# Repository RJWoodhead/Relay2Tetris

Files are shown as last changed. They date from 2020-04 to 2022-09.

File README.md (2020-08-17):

# Relay2Tetris

In 2019, I had the great privilege of being able to see the [FACOM 128B](/Documents/FACOM-128B.pdf) computer in operation at Fujitsu's company museum. Delving into the technical details of how this machine worked only increased my admiration for the engineers who designed it. This has inspired me to create my own relay-based computer as a hobby project.

A few years prior I was introduced to the [Nand2Tetris](https://www.nand2tetris.org/) course, which I highly recommend. The HACK CPU that students implement in the course is a masterpiece of minimalist CPU design, so it was a natural target for my ambitions.

The goal of this project is to completely implement the HACK CPU in relay logic, and also to provide other relay-computer builders with a set of standard board-level relay logic CPU components, such as registers, adders, and so on.

# August 2020 Project Status Video

YouTube Video (https://youtu.be/P-tVBMidEhQ)

# Project Reports

* [Conversion of the idealized HACK CPU architecture to a physical model that addresses timing considerations](/Design.md).
* [Component-level HACK simulator](/Simulator.md).
* [40-Channel Daisy-chainable Raspberry Pi IO Expansion Board](/IOExpander.md).
* [The War on Voltage Drop](/Voltage.md).
* [Register Board](/Register.md).
* [Zuse Adder/Subtractor/Incrementor](/ZuseAdder.md).
* [8 Function Boolean Logic Unit](/LogicUnit.md).
* [2:1 Mux + NOT / Breadboard](/MuxNot.md).
* [Arithmetic-Logic Unit](/ALU.md).

# Reference Files

* [Useful EasyEDA scripts](/EasyEDA.md).
* [Hardware Test scripts)(HardwareTests).
* [Gerber Files for all boards](/Gerber).
* [Bills of Materials for all boards](/BOMs). (Note: does not include optional components like relay coil voltage drop resistors, voltage regulators, etc., as they will rarely if ever be needed. BOMs are for fully-populated boards including any breadboard relays)
* [Datasheets for various hardware components](/Datasheets).
* [YouTube project playlist](https://www.youtube.com/playlist?list=PL5v_4nsiG1zsZgzh9NE4S_au2oJwVJGt1).

The fleshing-out of this archive is an ongoing project; please be patient with the author.

# Recent Update History

2020-08-17: Assembled and tested the [Arithmetic-Logic Unit](/ALU.md).

2020-08-06: Updated all the board design documents, improved the hardware tests, did some project cleanups. Added a project status video.

2020-07-20: Launched the [War on Voltage Drop](/Voltage.md). Redesigned all boards based on the results (see individual board pages for details). Created new IO Expander Daughterboard. Added BOMs for all boards.

# To-Do List

* Clock and Sequencer - in design.
* Program Counter & Branch Unit - in assembly.
* Program ROM and RAM - optional, may design as proof of concept.

# Surplus Board Availability

Due to minimum quantity requirements, I have extras of most of the various versions of the various boards. If you want one, email me at trebor@animeigo.com and we'll work something out.

# Acknowledgements

Given that I am a programmer by trade, and thus a clueless n00b at hardware design, I am indebted to those who know better than me, including, but not limited to:

[Harry Porter's Relay Computer Project](http://web.cecs.pdx.edu/~harry/Relay/) and [Technical Paper](http://web.cecs.pdx.edu/~harry/Relay/RelayPaper.pdf)

[The Relay Computer Blog](https://relaycomputer.co.uk/)

[The Clicks Relay CPU](http://clicksrelaycpu.blogspot.com/?view=classic)

FACOM 128B Information:

* http://museum.ipsj.or.jp/en/computer/dawn/0012.html
* https://hackaday.com/2019/12/06/visiting-the-facom-128b-1958-relay-computer/

The complete Nand2Tetris course can be found at: https://www.nand2tetris.org/

# License

The materials in this repository (except for those provided by outside sources) are licensed under the [Creative Commons Attribution-NonCommercial-ShareAlike 4.0 International (CC BY-NC-SA 4.0)](https://creativecommons.org/licenses/by-nc-sa/4.0/).

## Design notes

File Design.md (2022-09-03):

# HACK CPU design

The [HACK CPU](https://www.nand2tetris.org/project05) is a minimalist CPU design, but for simplicity, the Nand2Tetris hardware simulator assumes idealized hardware with no gate delays. In the real world of clicky relays, a more detailed design is required. In particular, extra internal registers are needed to break up potential cycles (such as when a register is both the input to and destination of an ALU operation).

This design is a work-in-progress and will undergo significant revision as the actual hardware gets built.

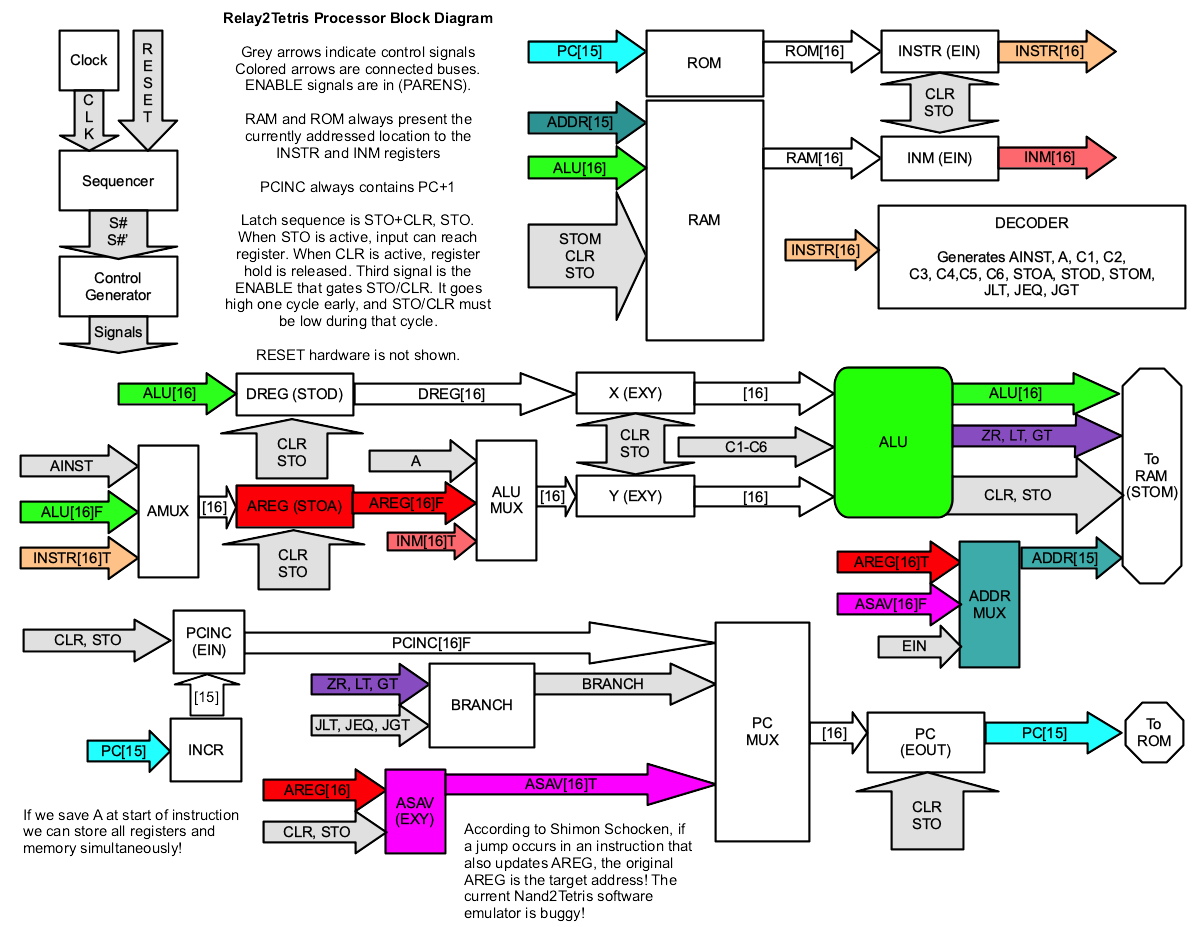
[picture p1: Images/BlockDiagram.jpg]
Block diagram for the expanded design


The computer a "tick-tock" clock that sequences through an 10-state loop per instruction. The states are then converted into control signals via a matrix or finite-state machine.

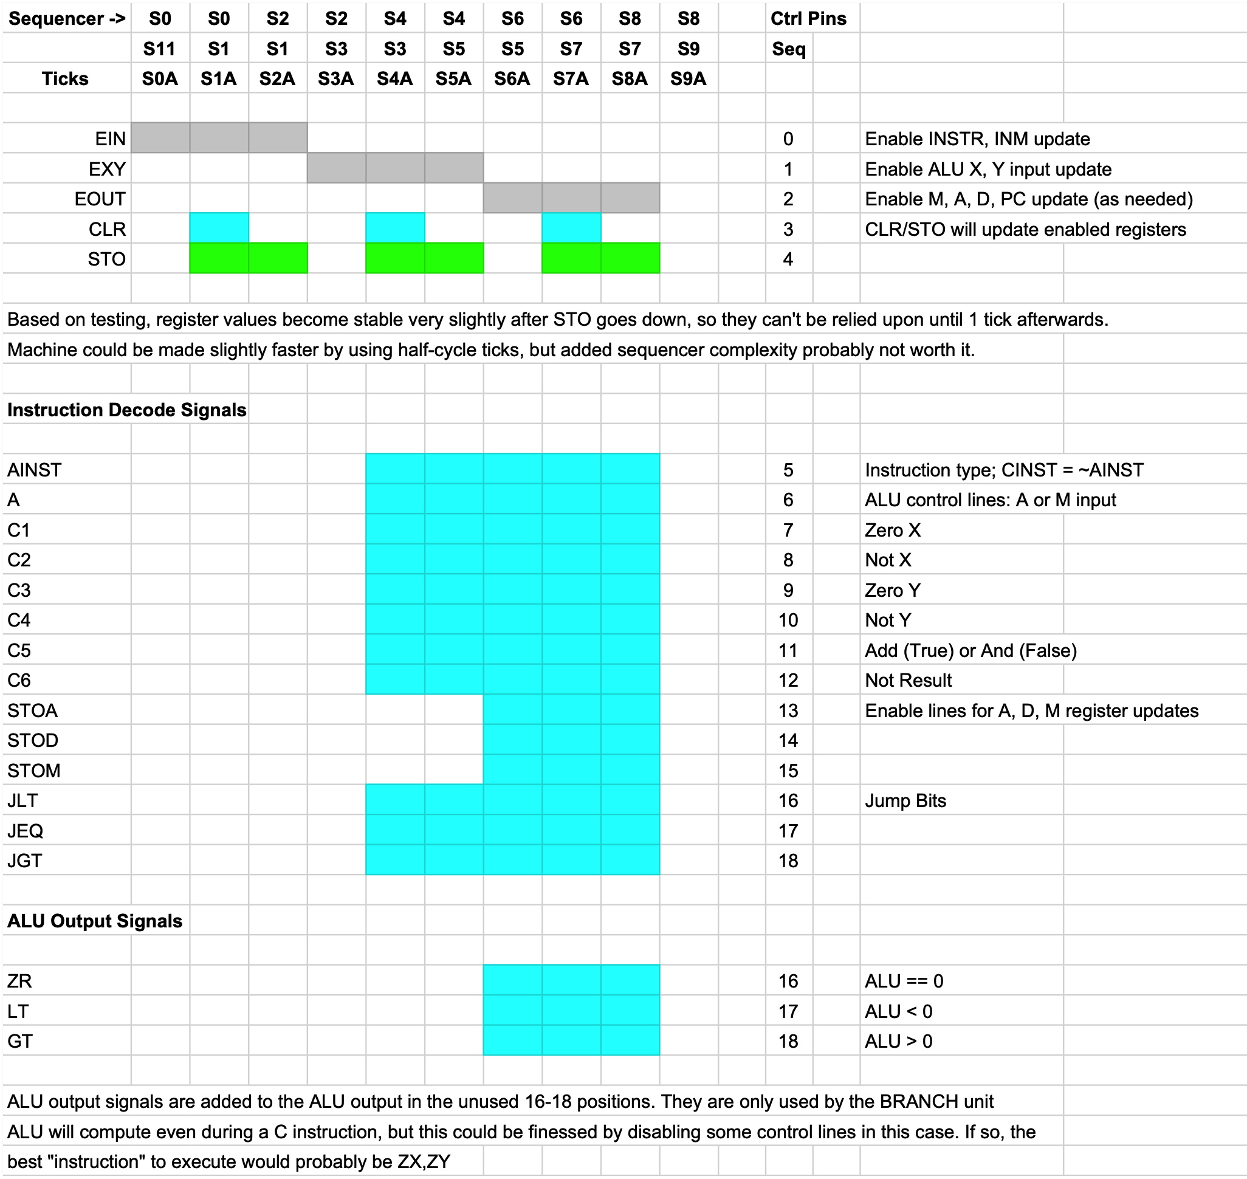
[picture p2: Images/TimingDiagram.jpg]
Instruction State Matrix


The clock and sequencer design will be heavily influenced by the excellent work done on the [Relay Computer Blog](https://relaycomputer.co.uk/2014/09/sequencing-control-design-overview).

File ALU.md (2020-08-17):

# Arithmetic-Logic Unit Assembly

The ALU is the first multi-board assembly in the project. It consists of:

* Two input data registers, X and Y. In the full computer, the X register is loaded with the value of D,
and the Y register is loaded with either A or M (using a multiplexer to select the desired input).

* Two Mux-Not boards, ZXNX and ZYNY. These first use the multiplexer to select either the input data or zero,
and then the Not unit to optionally negate the result. Thus, the ZXNX board can generate 0, -1, X and ~X,
and the ZYNY unit can generate 0, -1, Y and ~Y.

* An AND board and an ADD board, both of which are fed the outputs of ZXNX and ZYNY.

* A final Mux-Not board, which selects either desired AND or ADD output, and then optionally negates it.
This generates the output data value.

The ALU thus has 6 control lines, ZX (Zero X), NX (Negate X), ZY (Zero Y), NY (Negate Y), ADD (if 0, the AND output is used),
and NR (Not Result).

Surprisingly, the resulting ALU can compute all of the following values:

0, 1, -1, X, Y, ~X, ~Y, -X, -Y, X+1, Y+1, X-1, Y-1, X+Y, X-Y, Y-X, X&Y and X|Y

Actually, these are just the operations that are defined as part of the Hack machine language.
There are also some other [undefined operations of various utility](https://medium.com/@MadOverlord/14-nand2tetris-opcodes-they-dont-want-you-to-know-about-f3246831d1d1) that the ALU can perform.

# Physical Assembly

The boards are assembled using some [simple 3D-printed brackets](/STL) and connected using custom IDC cables.

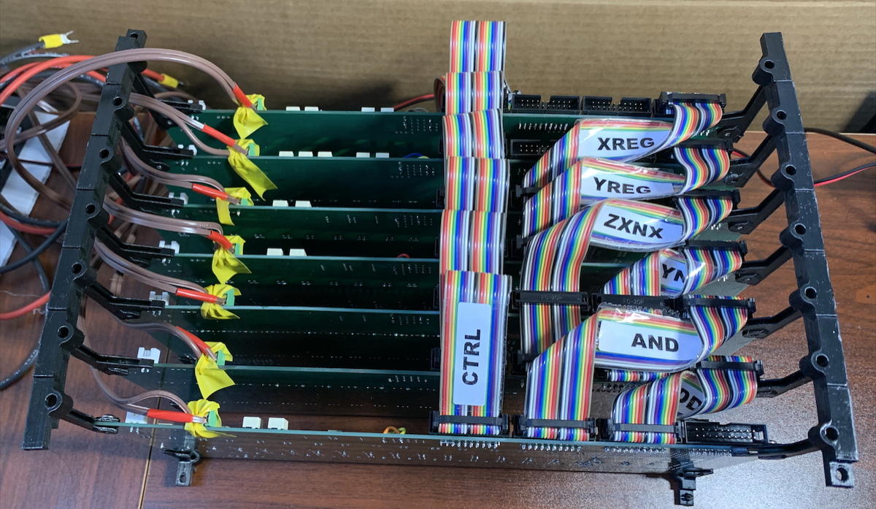
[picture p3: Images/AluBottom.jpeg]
16 Bit Logic Unit 1.0


# Testing

The ALU flawlessly completes the test script at a clock speed of 100 hz; it starts to become slightly unreliable at ~200 hz. Voltage drops are negligible, typically 100-150 millivolts. The drivers on the IO Expander provide a little over 10 volts when driven by the 12 volt input, but have no problems driving the control relays on the all boards. This bodes well.

Here is a video of the board being exercised.

YouTube Video (https://youtu.be/6PPwGQYELfU)

# Resources

* [Board Test Script](/HardwareTests/ALU.py).

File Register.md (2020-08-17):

# 16 Bit Register

Note: Please read [The War on Voltage Drop](Voltage.md) for context on the revision history of the PCB boards.

The Relay2Tetris project uses dual-pole, dual-throw (DPDT) relays. These have two independent circuits (the poles), each of which has an input and two outputs. When the relay is not energized, the inputs are connected to the normally-closed (NC) outputs, and when energized, the inputs are connected to the normally-open (NO) outputs.

The core element of the register is the self-latching relay circuit. In this circuit, when the BIT relay that holds the data is energized, one of the poles is used to complete a HOLD circuit that connects the relay coil to the power source. So once it gets energized, it stays energized. The second pole of the BIT relay is used to control the output of the register.

However, this circuit is also routed through the NC part of a second relay, the Clear (CLR) relay. Thus, when the CLR relay is energized, the HOLD circuit is broken. This circuit is hilighted in red in the illustration below.

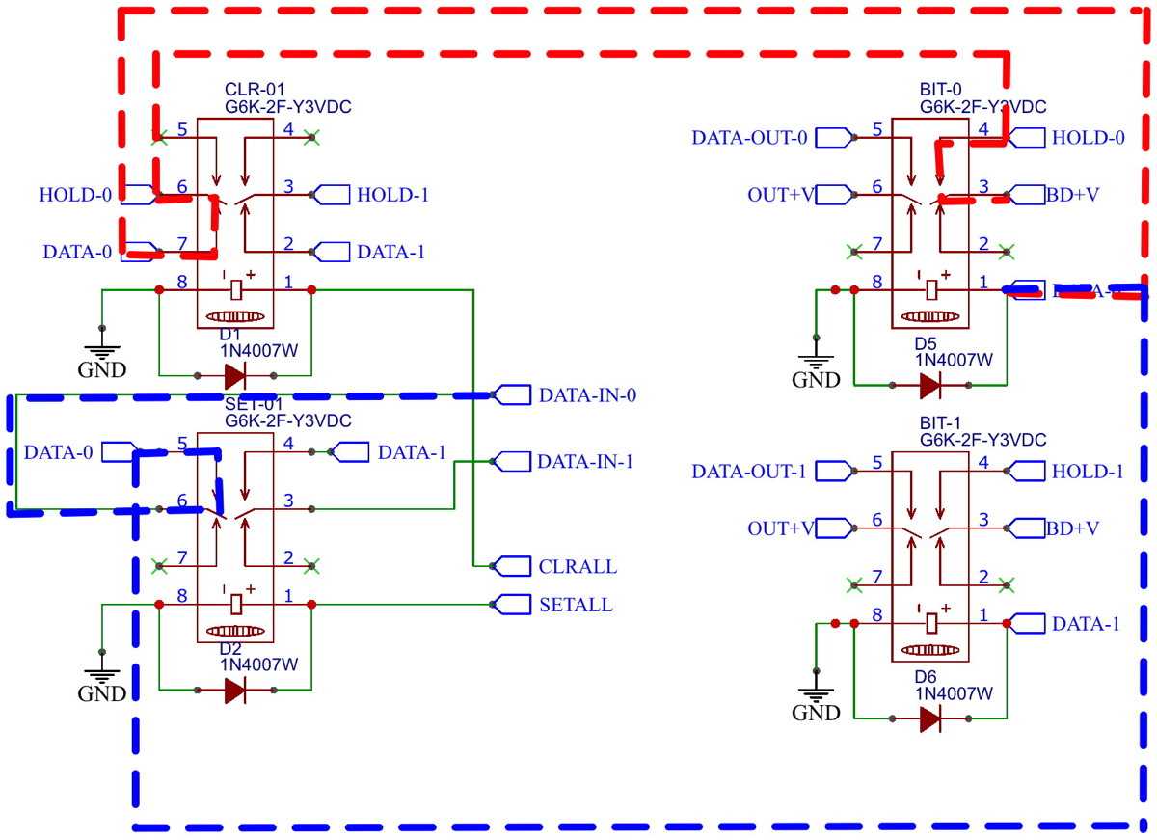
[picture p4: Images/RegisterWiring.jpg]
2 Bit Register Circuit


The second half of the circuit is the SET circuit. This is a relay that uses a NO part to gate the DATA-IN bit to the BIT relay coil, shown in blue above. When the relay is not energized, the BIT relay is isolated from the DATA-IN; it therefore maintains its state and is not affected by changes in DATA-IN.

Thus, the behavior of the circuit is as follows:

SET | CLR | Behavior
--- | --- | -------------------
Off | Off | BIT relays hold their value.
Off | On  | BIT relays reset to 0.
On  | Off | BIT relays are OR'd with incoming DATA
On  | On  | BIT relays are set to incoming DATA.

The usual control sequence for updating the register is thus SET+CLR (to replace the contents of the register), followed by SET alone (to ensure the data is being maintained by the HOLD circuit), followed by neither (to isolate the register from the inputs).

Since the CLR and SET relays have two poles, they can support two BIT relays. Thus, the basic building block is a 4-relay unit that stores 2 bits.

Repeat this 2-bit register 8 times, and the result is a 16-bit register.

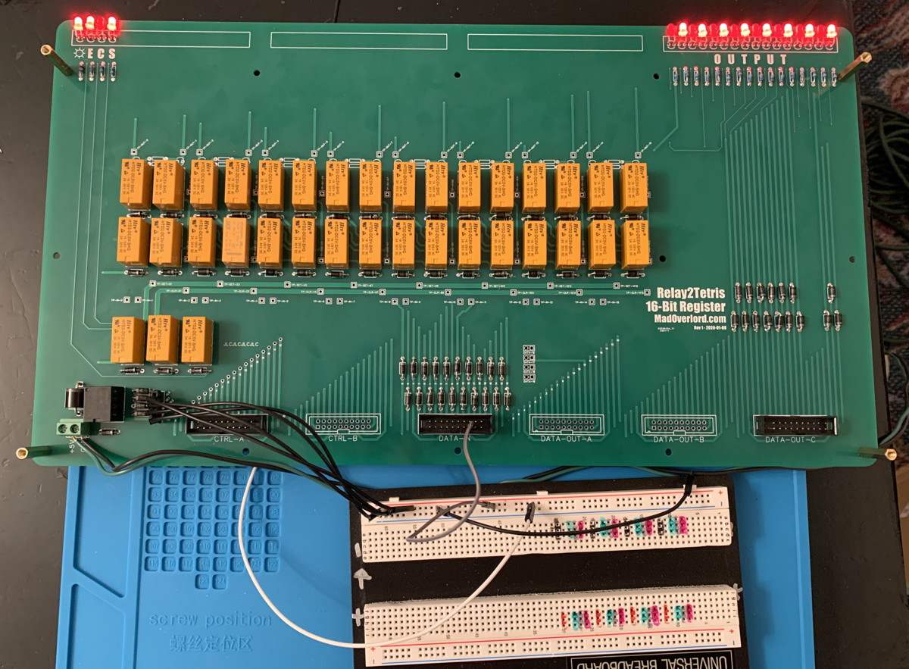
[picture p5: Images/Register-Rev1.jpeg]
16 Bit Register Rev 1.0


The Revision 1.0 board used inexpensive 5V through-hole relays. While fully functional, I did run into a few problems, the most confusing one being a voltage drop "gotcha" with the MIC2981 driver chips (see the [IOExpander](/IOExpander.md) writeup for details). After experimenting with the board at length, I designed a Revision 2.0 board that used 3V relays, and also moved to using surface mount components.

This allowed me to increase the component density and shrink the board significantly. Also, the 3V relays, while 3x as expensive as the cheap 5V ones, also switch 4x faster! So all in all, a good deal! In addition, I added a optional 2:1 multiplexer on the DATA-IN lines, as many of the registers in the final design have two possible inputs.

# Revision 2.0 Features (many of these also in 1.0)

* Onboard 3V3 regulator.

* Optional diode isolation of inputs and outputs.

* Control signals are ACT (Active, board is powered), ENA (Enable, board responds to control signals), SET, CLR, and MUX (controls whether DATA-0 or DATA-1 input is read). ACT and ENA can be jumpered to be always-on.

* All control inputs power isolation relays; this means an input signal only has to power one relay, even if the signal controls multiple relays on the board. This minimizes the current flowing through the ribbon cables. So for example, the SET control signal activates a single SETALL relay; that relay controls the 8 SET relays on the board. Each relay draws about 33 milli-amps @ 3V, and each relay contact is limited to about 1 amp, so using both contacts on a relay, you can source 2 amps = 60 relays using a single isolation relay. In practice, you don't want to approach this, so ~40 relays per isolation relay is a reasonable limit. The 16-bit register board has 40 relays driven by power sourced from the ACT relay.

* Control signals set by jumpers.

* Optional 2:1 Input Multiplexer.

* Optional signal passthrough connectors.

* Jumperable passthrough of the 4 unused IDC-20 signal lines on input to output.

* 3V0 relays running at ~3V3. Selectable 3V3 or 5V0 signal output.

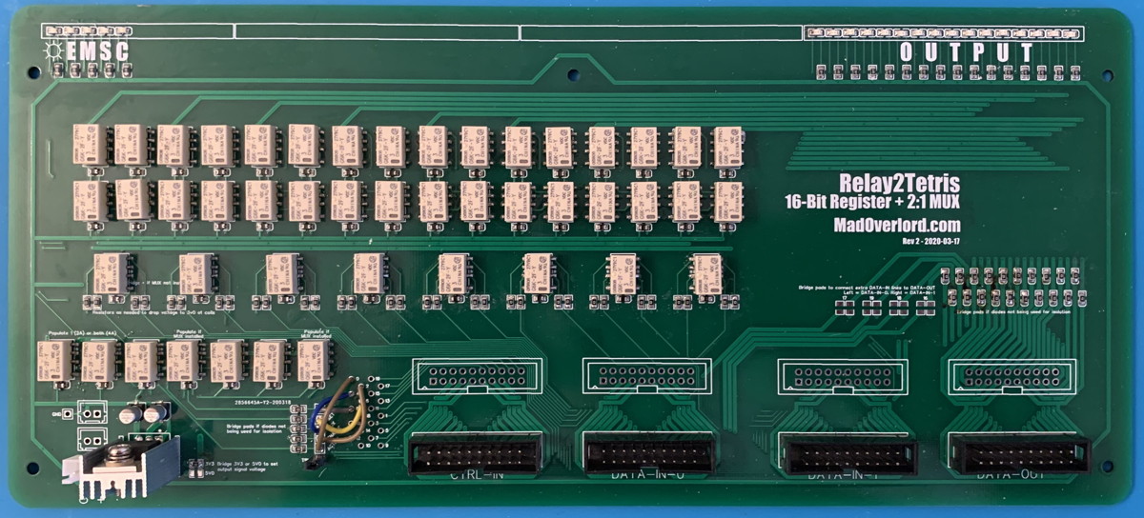
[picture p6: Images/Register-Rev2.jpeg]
16 Bit Register Rev 2.0


A detailed [Board Test Script](/HardwareTests/Register16.py) is also available. It requires my IOExpander board.

YouTube Video (https://www.youtube.com/watch?v=gMaYLL4p_do)

A short video showing the Revision 2.0 board being tested is available on [YouTube](https://www.youtube.com/watch?v=gMaYLL4p_do).

# Revision 3.0

Based on my experience with the Revision 1.0 and 2.0 boards, I have designed a Revision 3.0 board with several improvements:

* Removed signal passthrough connectors because that function can be handled with custom cables that are easier to configure.

* Removed power isolation relays, they are not really needed.

* Removed input and output isolation diodes as they are not needed in boards where the inputs are isolated via relays and the outputs do not connect to relay coils, so backfeed to relays is not possible. I had read that backfeed was an issue with relay circuits but I went overboard and didn't think it all the way through. A version of the Rev 3.0 board with isolation relays is available in the EasyEda project in case it is needed for a specific board.

* Changed ENABLE relay so that it controls the SET and CLR relays by disconnecting their GND connections.

* Changed trace sizes to match the expected current loads.

* Made 3V3 regulator optional.

* Moved passthrough jumpers to the rear of the board where possible to save space.

* Eliminated passthrough of pins 17-20 on the IDC connector (again, can be done with cabling), but added jumpers to connect 3V3 and GND to pins 19 and 20. This may be handy if using the output to directly drive a small satellite component, such as a display board.

* Moved traces closer to the edge of the board and rearranged everything to maximize the central area available for a relay array. Currently can handle a grid of 23x6 relays.

I have not yet manufactured any Revision 3.0 boards, but the designs are contained in the EasyEda projects (links below). The core layout (which is actually an edge layout!) will be used in subsequent functional boards.

Note: It turns out there is a design error with the ENABLE circuit in the Rev 3.0 boards that I am working on addressing. See [this note](LogicUnit.md#board-design-mistake) for more details.

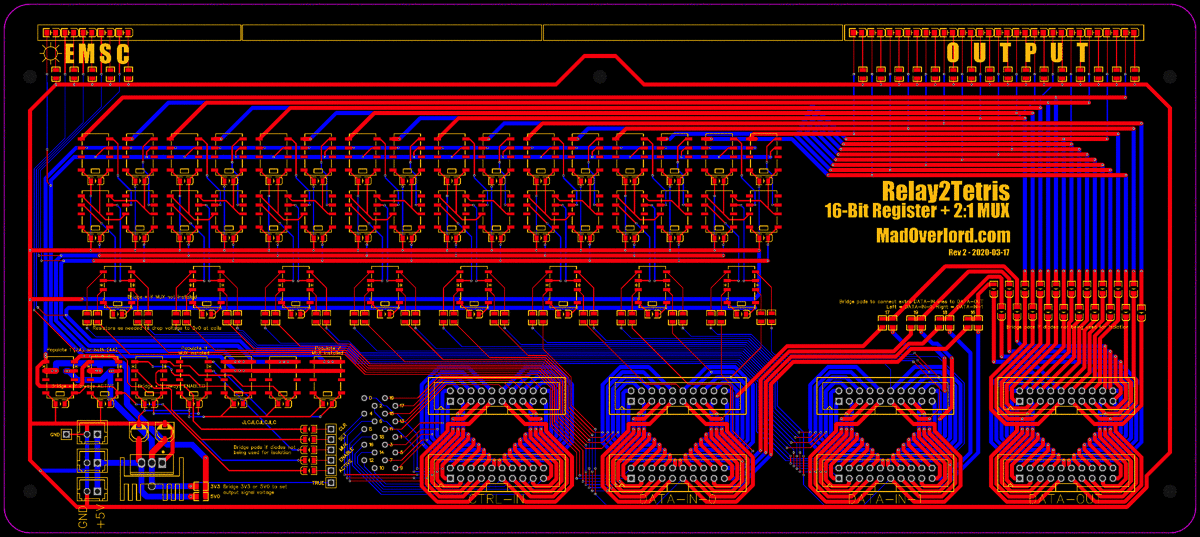
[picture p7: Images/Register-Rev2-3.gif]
16 Bit Register Rev 2.0/3.0 Comparison


# Revision 4.x

As a consequence of the [The War on Voltage Drop](Voltage.md), the Rev 4.0 board has many improvements:

* Fatter traces to reduce resistance of signal wires.

* Two voltage supply inputs, one of which can be regulated. Board voltage and output voltage can be selected from these.

* Removed ACTIVE signal as it is not really needed.

* Added RESET signal that clears register even when ENABLE is not raised. In the 4.0 board, the RESET may not work correctly if both ENABLE and SET are also raised and the data bus is non-zero. In practice this should not be a problem since RESET would be raised for many cycles, but this has been fixed in the 4.1 board.

* Since there was space on the board, also added a bit test functional unit. There are two independent test channels (one for each pole in the relays), and for each bit position you can specify that the bit has to be True, False, or Don't Care. The tests can also be set up into subtests that only look at a sequence of bits (so you can test high and low bytes separately, for example). Finally, there are outputs for each of the bits, two additional relays for implementing special purpose logic, and you can then jumper all of these to indicator leds and the upper 4 bits of the 20 pin IDC data connectors as well as any of the control lines. A typical use for this would be detecting when the register is zero or negative.

* In the 4.1 revision, unused parts of the board have been filled with additional breadboard relays.

* In 4.2, improvements were made to the board silkscreen labels (but no layout changes).

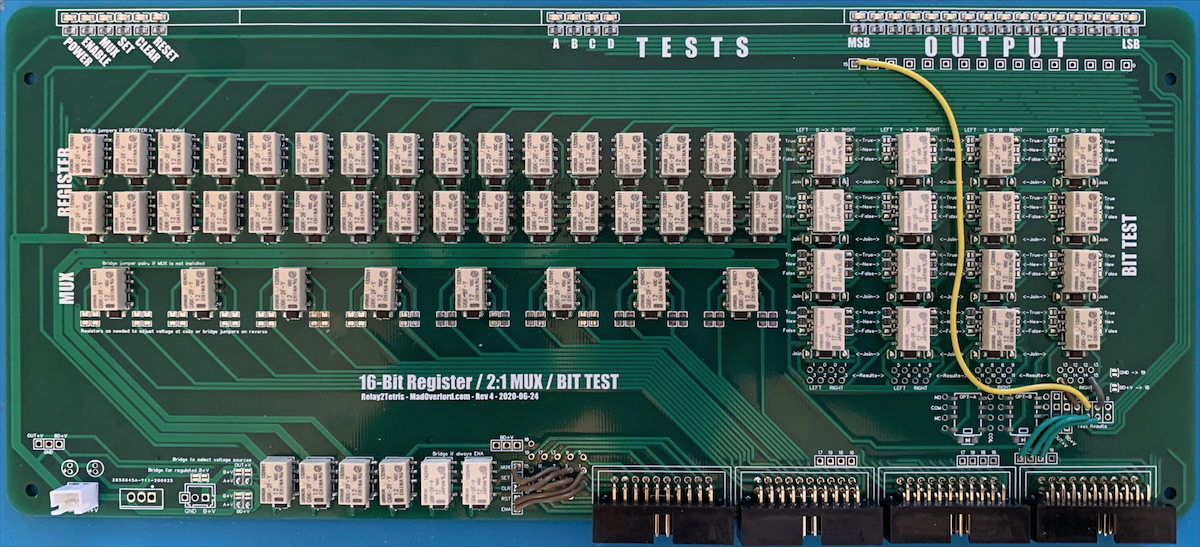
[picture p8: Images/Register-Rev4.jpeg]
16 Bit Register Rev 4.0


In the above image, the board is wired to detect 0, -1, and <0.

# Resources

* [Board Test Script](/HardwareTests/Register16.py).

* [EasyEda Project](https://easyeda.com/MadOverlord/16-bit-register), [Gerber Files](/Gerber/Register.zip) and [BOM](/BOMs/Register.csv) for the latest revision of the board.

* Boards were manufactured by [JLCPCB](https://jlcpcb.com/). Parts were sourced from [LCSC](https://lcsc.com/) and [Digikey](https://www.digikey.com/).

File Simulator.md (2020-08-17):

The [Relay2Tetris simulator](/Simulators) simulates the proposed HACK CPU implementation at the board-level, and updates the state of control signals and component inputs and output every clock tick.

Eventually, this simulator will have the ability to interface with the actual hardware, and gradually migrate more and more component functions to the actual device.

The Tests subdirectory contains a set of test programs for the simulator, adapted from the Nand2Tetris HACK tests.

**NOTE**: The current version of the simulator is running an older version of the hardware design that does not match the [current design](design.md). The simulator will be updated to match the hardware design when larger chunks of the hardware are being integrated.

# Running the simulator

Usage: python3 validate.py [Test name (subfolder of Tests folder)] {Trace Level: [N]one|[I]nstruction|[C]lock|[S]ettle}

Test folder [xxx] will contain up to 4 files.

* [xxx].hack : The machine code source file (output of the Nand2Tetris assembler) - required

* [xxx].asm : Human-readable source code (input to the Nand2Tetris assembler)

* [xxx].tst : Validation test script (input to the Nand2Tetris emulator)

* [xxx].cmp : Validation comparison results

If [xxx].tst is present, the validator runs the test script and compares the output to the contents of the [xxx].cmp file. If not, the validator just runs the machine code.

To make parsing simpler, there is a restriction on the test scripts: there can be only one output-list, and the formatting is ignored.

The load, output-file, and compare-to commands are ignored because they are implied by the files in the test folder, and these files need to be loaded before the script is executed.

For convenience, the validator recognizes when the machine has entered the infinite-loop end condition and exits script repeat loops early in this situation.

The default trace level is [I]nstruction, which provides machine state at the start of each instruction cycle. [C]lock lets you see the internal state of all signals at each machine clock. [S]ettle shows that plus the process of settling on the hardware state. [N]one just reports the results of the validation.

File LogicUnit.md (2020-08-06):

# 8 Function Logic Unit

Note: Please read [The War on Voltage Drop](Voltage.md) for context on the revision history of the PCB boards.

This board generates the 6 useful logic functions (AND, OR, XOR, NAND, NOR and XNOR) as well as the two useless ones (TRUE and FALSE) on two 16-bit inputs.

# Revision 1.0

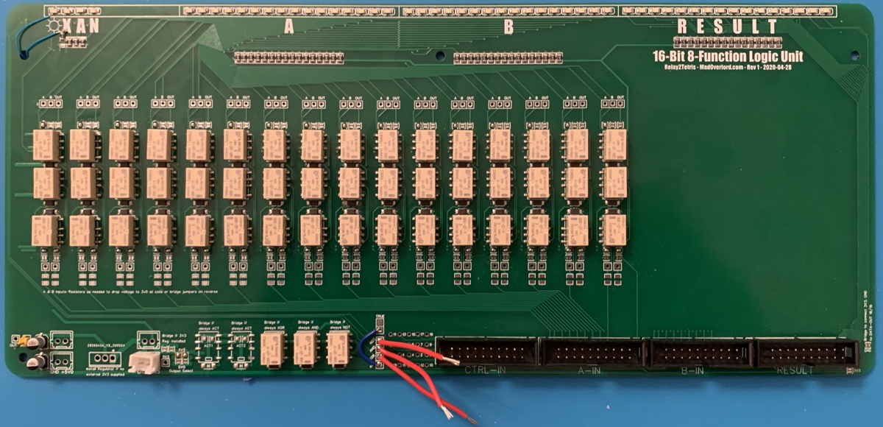
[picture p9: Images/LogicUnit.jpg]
16 Bit Logic Unit 1.0


Operation selection is done through 3 control signals (AND, XOR, and NOT). There are two stages to the unit; in the first, AND and XOR are computed as needed;
they are then OR'd and optionally NOTted. OR is generated by computing both AND and XOR at the same time.

The circuit design is inspired by the Zuse adder, in that the operation selection signals for AND and XOR energize two circuit paths, and the state of two relays
is controlled by the input bits; this determines whether or not the signals get through the relays to the NOT relay. Since AND and XOR are exclusive to each other (AND(a,b) != XOR(a,b)), there is no possibility of backfeed between the circuits and their outputs can simply be connected together to OR them.

That said, my battles with backfeed are not over; see below for an important gotcha!

The desired operation can be hardwired for the entire board or on a per-bit basis using solder bridges.

YouTube Video (https://youtu.be/KSzZ73obGIc)

A short video showing the Revision 1.0 board being tested is available on [YouTube](https://youtu.be/KSzZ73obGIc).

# Board Design Mistakes

One of my goals with the board design was to minimize power usage by disabling relays when the board was not ACTIVE. This was done by routing all of the relay grounds onto
an ENABLE circuit, and connecting that to GND via a relay. If that relay wasn't activated, no connection to GND, and none of the other relays could operate.

This design fails if there is any connection, however convoluted, between the ENABLE circuit and GND. And unfortunately, when the board is connected to the IO Expander (and thus,
the Raspberry Pi), there is such a connection: backwards through any relay coil, out through one of the connectors, to the IO Expander, and then through the data line's pulldown
resistor!

To paraphrase Ian Malcolm, "Electricity finds a way." :(

This situation is made even worse because +3V3 is routed through the ACTIVE LED to the ENABLE circuit. This means that when the board is connected to the IO Expander, that LED
(and some of the DATA leds) glow faintly.

The board still operates as expected, but the mistake is troubling and it's a recipe for weird problems down the line. Thus I am redesigning this board, and all the other boards
that I revised to use this ENABLE system, so that all relays always connect directly to GND.

In the meantime, the workaround is to not install the ENABLE relays and solder-bridge the board so it's always ENABLED. This makes the ENABLE circuit equivalent to GND.

A second error is that if the NOT relay is not populated, and NOT is not activated, the NC relay connections need to be bridged in order for the other logical functions to operate properly. I omitted solder jumpers for this functionality. The workaround is to use some 0-ohm SMT resistors as jumper wires.

# Revision 2.0

16 Bit Logic Unit 2.0

Revision 2.0 of the board incorporates all of the lessons learned during the War on Voltage Drop. In addition, the unused space on the board has been filled with a relay breadboard that may come in handy; this is configured like the bit test unit on the register board, so it can easily be wired to do bit value tests if needed.

This board has been manufactured and tested. The only mistake I've noticed so far is that I swapped the labels on the ALWAYS and NEVER NOT-Control jumpers. This has been corrected in the 2.1 revision.

# Resources

* [Board Test Script](/HardwareTests/LogicUnit.py).

* [EasyEda Project](https://easyeda.com/MadOverlord/relay-boolean-logic-unit), [Gerber Files](/Gerber/Logic.zip) and [BOM](/BOMs/Logic.csv) for the latest boards.

* Boards were manufactured by [JLCPCB](https://jlcpcb.com/). Parts were sourced from [LCSC](https://lcsc.com/) and [Digikey](https://www.digikey.com/).

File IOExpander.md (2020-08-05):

# Raspberry Pi 40-channel IO Expander

In order to control and test the relay-based functional modules this project will require, the ability to control a large number of data channels is required. For example, the 16-bit register board requires 2 16-bit data inputs, 5 bits of control input, and produces 16 bits of data output.

This is far more channels than the Raspberry Pi natively provides, and so some sort of IO Expansion device is needed.

*Note: I am not an electrical engineer. Everything I've learned has been from reading and trying things out. Therefore, take everything here with a grain of salt. That said, so far it's worked really well!*

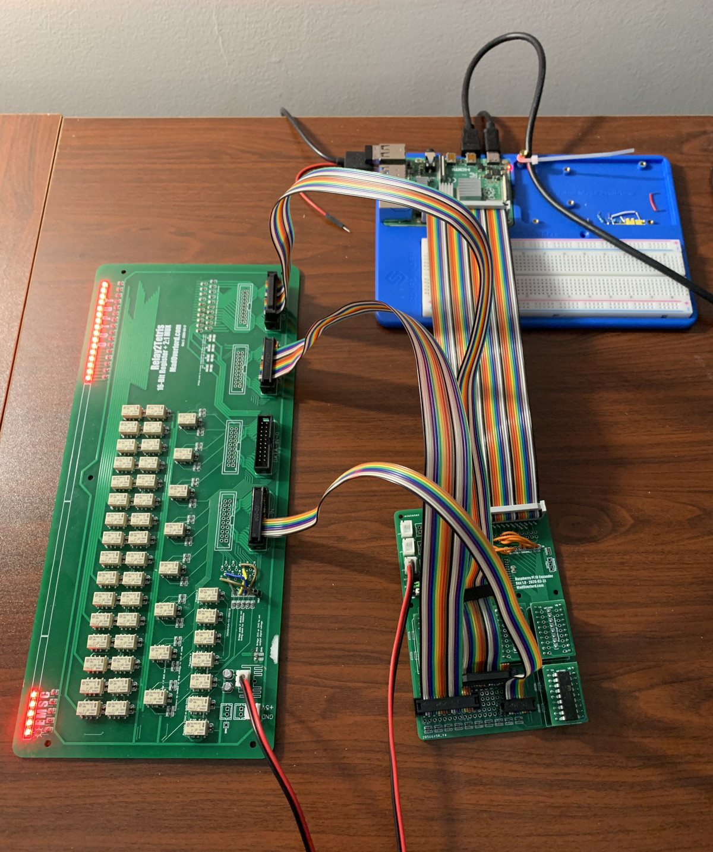
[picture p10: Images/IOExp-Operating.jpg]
Operating IO Expander


The common approach in this situation is to use one or more [MCP23017](/Datasheets/MCP23017.pdf) bidirectional IO port chips; each provides 16 channels, and up to 8 can be connected to the Raspberry Pi. However, controlling relays adds a layer of complexity because each relay requires ~30ma of current and the maximum amount of current the chip can provide is 25ma per pin, and 125ma total.

Another chip that people often use when connecting circuits to the Raspberry Pi is the [TXS0108e](/Datasheets/txs0108e.pdf) bidirectional level converter. It is an 8-channel chip that can increase or reduce the voltage of a signal, so it can (for example) convert from 3.3v to 5.0v. However, it too is limited to 50ma per signal and 100ma total.

Therefore, to drive relays, we need to put something between the MCP23017 and the relays that can provide the needed current. What I settled on was the [MIC2981](/Datasheets/mic2981.pdf) driver array; it can provide 8 channels of up to 500ma per channel.

* **One thing about the MIC2981 to be aware of**: under load, the output voltage on a signal line will sag from 1.5-2.0v. On the datasheet, this is cryptically (to a n00b like me) listed as "Collector-Emitter Saturation Voltage". What this means is that if you power the chip at 5v0 (5 volts), what your relays will see is ~3V3 (3.3 volts), which is at the low end of what the relay will respond to. And since the sag is affected by the total amount of current the chip is sourcing, the more signal lines that are high, the lower the voltage on those lines. Before I understood this, I was going nuts trying to figure out why Revision 1 of my relay register board (which used 5V relays) would become unreliable when I asked it to store numbers with lots of set bits! The solution is to provide the MIC2981 with about 1.7v more input voltage than the desired output voltage. In my case, to keep things simple, in the Revision 2 relay board (shown above), I provide 5V0 to the MIC2981 chips, and use 3V relays on the board (which are comfortable with voltages up to 4.5v, so giving them 3.3-3.5v is fine). This also lets me use a standard PC power supply, which provides both 3V3 and 5V0.

* As explained in [The War on Voltage Drop](Voltage.md), this turned out to be a mistake.

I tested using the MCP23017/MIC2981 combination on a breadboard, and then built a project-board version that was a complete rats-nest of wires. It worked, but it certainly wasn't pretty. Since I was going to need a significant number of IO channels, I decided to build a PCB version of the IO expander. This is what I came up with:

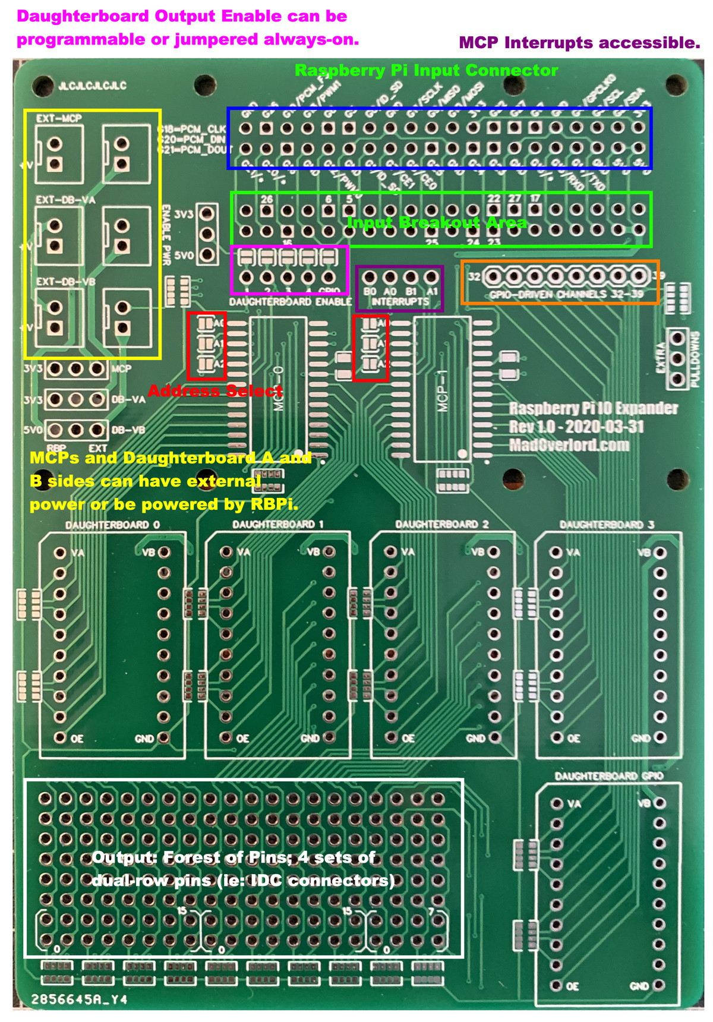
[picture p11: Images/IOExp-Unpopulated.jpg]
Unpopulated IO Expander


This board supports two MCP23017 chips (2x16 channels) plus 8 channels of direct GPIO from the Raspberry Pi. Up to 4 boards can be daisy-chained together. So you can have up to 128 bits of MCP IO, plus all the usual GPIO IO.

Features include:

* For flexibility, each group of 8 channels is routed through a small daughterboard, which is configured to accept one of the TXS0108e daughterboards that are commonly available from lots of different suppliers. In addition, I designed a compatible daughterboard that will accept a MIC2981 or can be jumpered as a passive passthrough. The daughterboard uses the through-hole variant of the MIC2981 because (a) I had some of them and (b) they are slightly cheaper than the surface mount version. Later on, I also created a voltage divider daughterboard for reducing the voltage of input signals.

  * There are pulldown resistor arrays on the input (MCP or GPIO) side of each daughterboard socket. My experience is that you need them for active devices like the MIC2981, but not for passives like the voltage divider (which is in effect its own pulldown). In particular, if you don't have the pulldowns on MIC2981s being driven by the RBP's GPIO, when you do a GPIO.cleanup() and the pins go to input mode, the MIC2981 inputs will float, and you may get spurious outputs.

* A forest of output pins make it easy to install IDC-style headers, or wire up custom connectors. The outputs also have a set of resistor arrays for output pulldown.

* The MCPs and the A and B sides of the daughterboards can receive their power from the Raspberry Pi or an external power source.

* The Enable signals that the TXS0108e boards require can be jumpered always-on or controlled by GPIO signals.

* Mounting holes for a Raspberry Pi. Typically, you'd mount the Pi above the IO Expander, so the Expander isn't a "Hat", it's a "Shoe".

A detailed [Board Test Script](/HardwareTests/MCPLoopback.py) is also available.

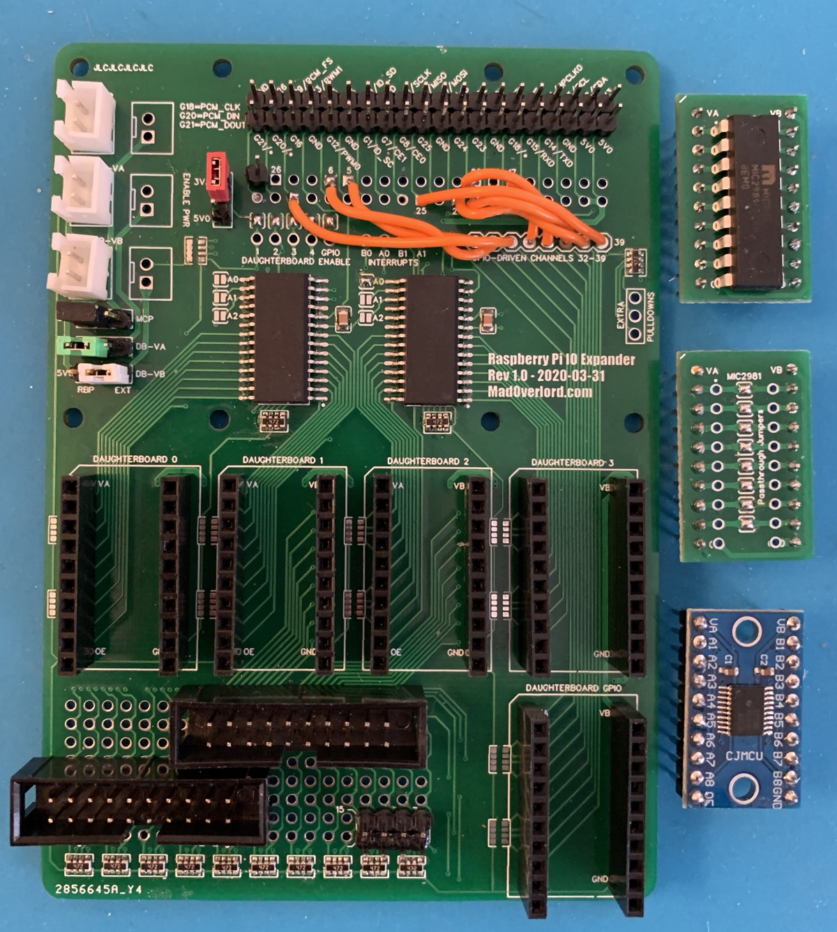
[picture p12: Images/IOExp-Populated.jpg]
Populated IO Expander


# Random Things I Learned

These are very simple things. Marvel at my n00bitude.

* Surface mount soldering is fun and easy, but the 0603 resistor arrays are a bit finicky; they tend to accumulate solder bridges. Using a pencil-tip soldering iron set at 280c and flicking the tip between bridged pads is a quick way to eliminate the bridges.

* You can test for bridges on the resistor arrays by measuring the resistance between adjacent pins on the non-ground side; if there is no bridge, the reading will be about 2x the resistor value. Note that this won't work on the first two pins of the arrays below the MCP pins, as the first pin is separate; it's connected to +V and the ~RESET line of the chip.

* The easy way to connect the solder jumpers is to use the soldering iron to heat both pads and then feed some solder onto the tip while stirring it around, then removing the tip. You always need to add a little solder to the tip even if there already is some on it, because the flux in the fresh solder helps surface tension do its magic. I also took one of my fine tips and bent the end into an L-shape to make it easier to contact both of the pads at the same time.

# Revision 2.0

Based on my experience with the Revision 1.0 boards, I have designed a Revision 2.0 board with several improvements:

* Solder jumpers for common GPIO hookups (so no nest of wires like in my populated board).

* Optional pulldowns on the underside of the daughterboard on both input and output lines, which may be more convenient than the pulldowns on the mainboard.

* Extra mount hole in the lower part of the board for a support standoff when stacking boards.

I have not yet manufactured any Revision 2.0 boards, but the designs are contained in the EasyEda projects (links below).

Here is a complete "full stack" consisting of a Raspberry Pi 4 and 4 IO Expander boards. It provides 2 x 16 bit MCP outputs, 20+4 bits of GPIO output (all using the MIC2981 daughterboards so they can drive relays), and 6 x 16 bit MCP inputs.

# Voltage Dividing Daughterboard

As part of [The War on Voltage Drop](Voltage.md), I needed a way to convert 12V0 signals from the PCBs down to 3V3 so they could be safely read by the MCP chips. I did this with a simple voltage 8-channel voltage divider circuit. Links to the project and Gerber files below.

The PC power supply I am using delivers about 11.4 volts on its 12V0 output.

In turn, the MIC2981 drivers output about 9.9v when given this input when under load. This is enough to drive relays on a board, as they have a must-operate voltage of 80% = 9.6v. However, it is something to be aware of in more stressful situations. The solution will be to increase the supply voltage to the B side of the 2981s on the IO Expander board to ~14v. 2981s can accept up to 50v, so there's no problem there. The relays can tolerate 150% of rated voltage, so giving them 15-2=13v should not be a problem.

Using the Rev 4.0 register board, with input voltage of 11.4v, the output voltage at the data connector is 11.37, almost no drop. After the voltage divider, we are down to 3.17v, which is more than enough; the MCPs will reliably read data to about 55-60% of the 3v3 nominal voltage.

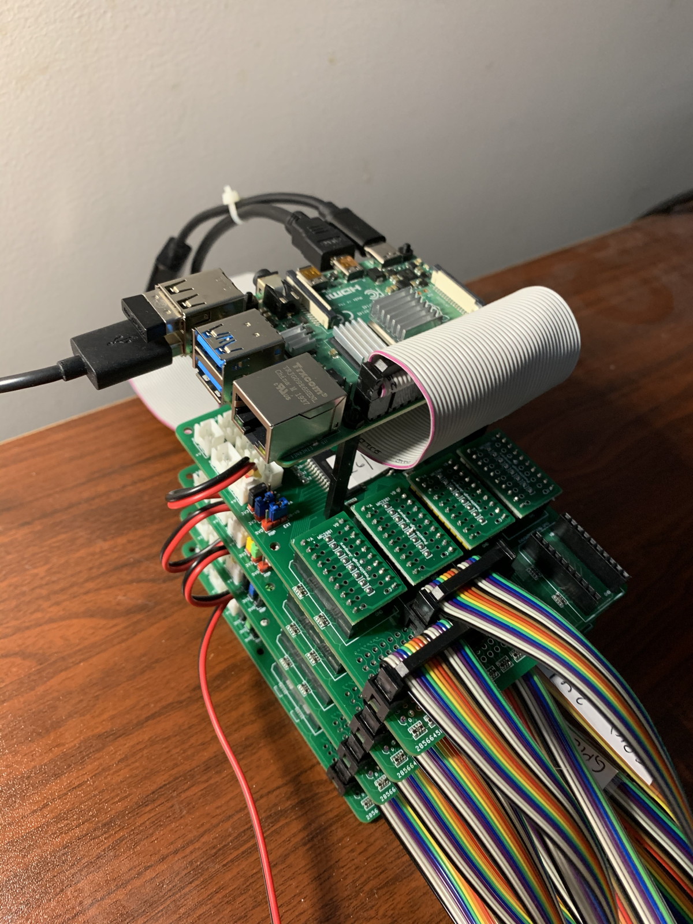
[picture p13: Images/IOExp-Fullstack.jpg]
IO Expander Stack


# Resources

* [Board Test Script](/HardwareTests/MCPLoopback.py)

* [Quick GPIO Test Skeleton](/HardwareTests/GPIO.py)

* IO Expander [EasyEda Project](https://easyeda.com/MadOverlord/rbp-io-expander), [Gerber Files](/Gerber/IO_Expander.zip) and [BOM](/BOMs/IO_Expander.csv).

* MIC2981 / Passthrough Daughterboard [EasyEda Project](https://easyeda.com/MadOverlord/io-expander-daughterboard), [Gerber Files](/Gerber/IO_Expander_Daughterboard.zip) and
[BOM](/BOMs/IO_Expander_Daughterboard.csv).

* Voltage Drop Daughterboard [EasyEda Project](https://easyeda.com/MadOverlord/io-expander-voltage-divider-daughterboard), [Gerber Files](/Gerber/IO_Expander_Voltage_Drop.zip) and
[BOM](/BOMs/IO_Expander_Voltage_Drop.csv).

* Boards were manufactured by [JLCPCB](https://jlcpcb.com/). Parts were sourced from [LCSC](https://lcsc.com/) and [Digikey](https://www.digikey.com/).

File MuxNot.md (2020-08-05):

# 2:1 Mux + NOT Board

Note: Please read [The War on Voltage Drop](Voltage.md) for context on the revision history of the PCB boards.

This board is pretty simple. It consists of a 2:1 input multiplexer connected to a NOT unit.

# Revision 1.0

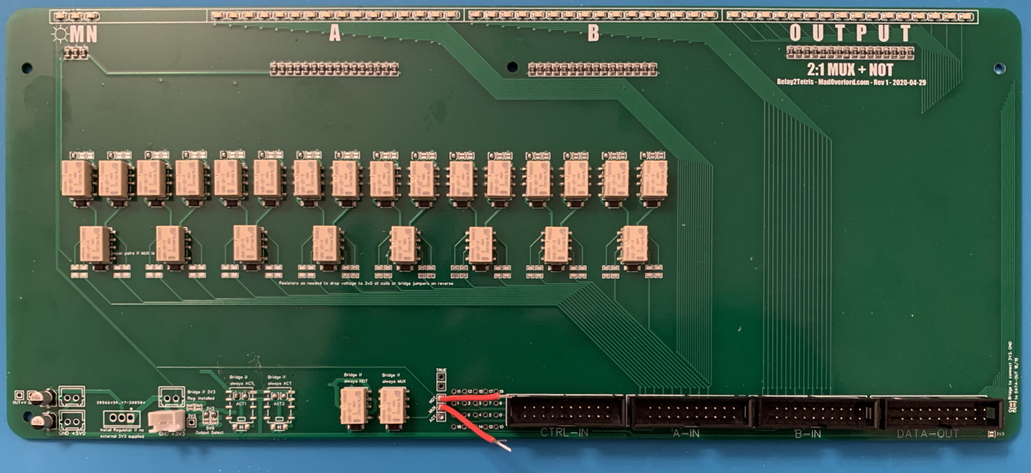
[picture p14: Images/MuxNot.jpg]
16 Bit Mux + Not 1.0


Two of these board will be used in the ALU to compute the ZERO and NOT operations on the X and Y inputs. ZERO is a simple matter of not connecting B-IN to anything! If the MUX bit is then set, the input to the NOT unit is all zeroes.

The desired operations can be hardwired for the entire board or on a per-bit basis using solder bridges.

YouTube Video (https://youtu.be/2-9iTJ1my6Y)

A short video showing the Revision 1.0 board being tested is available on [YouTube](https://youtu.be/2-9iTJ1my6Y).

Note: It turns out there is a design error with the ENABLE circuit in this board that I am working on addressing. See [this note](LogicUnit.md#board-design-mistake) for more details. The temporary workaround is to jumper the board so it is always ENABLEd.

# Revision 2.0

16 Bit Mux + Not 2.0

Revision 2.0 of the board incorporates all of the lessons learned during the War on Voltage Drop. In addition, the unused space on the board has been filled with a relay breadboard that may come in handy.

# Resources

* [Board Test Script](/HardwareTests/MuxNot.py).

* [EasyEda Project](https://easyeda.com/MadOverlord/16-bit-relay-2-1-mux-not), [Gerber Files](/Gerber/MuxNot.zip) and [BOM](/BOMS/MuxNot.csv) for the latest revisions.

* Boards were manufactured by [JLCPCB](https://jlcpcb.com/). Parts were sourced from [LCSC](https://lcsc.com/) and [Digikey](https://www.digikey.com/).

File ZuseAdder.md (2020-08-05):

# 16 Bit Zuse Adder

Note: Please read [The War on Voltage Drop](Voltage.md) for context on the revision history of the PCB boards.

The Zuse Adder is an amazing relay circuit created by computing pioneer [Konrad Zuse](https://en.wikipedia.org/wiki/Konrad_Zuse) in the late 1930s. A normal adder has 3 inputs (the two data bits A and B plus a carry-in bit) and two outputs (the result plus carry-out). This is quite straightforward, but suffers from the problem of carry-propagation delay. Each bit in the sum has to wait until the previous bit is computed in order to get its carry-in bit, so you have to wait for the carry states to ripple down the adder.

The Zuse Adder, on the other hand, has 5 inputs (the two data bits A and B, carry-in, **not-carry-in**, and true) and 3 outputs (the result, carry-out, and not-carry-out). By propagating both the carry state and its inverse, each bit adder always has at least 2 current sources (one of the carries plus the true input), and a clever combination of two 4PDT relays per bit can route these to the correct outputs (only two of which can be true), with no carry propagation delay (other than the electrons meandering down the circuit paths, of course).

It takes a while to wrap your head around exactly how this electromechanical magic trick works, but I've hilighted the connection paths in the [schematic PDF](/Documents/ZuseAdder.pdf) for each of the 8 possible cases.

* Note: I created an alternate EasyEDA schematic for the relays that organized the common and NO/NC contacts in a way that made the schematic simpler. It comes in two variants, one of which has the coils energized. This makes it easier to follow the connection paths.

But it gets better. Normally you set the inputs to the first bit of the adder to carry-in=OFF, not-carry-in=ON. But if you swap this and give the adder carry-in=ON, not-carry-in=OFF, it happily computes A+B+1. If you then set B=0, you have an A+1 incrementor.

And then it gets even better than that. In binary arithmetic, A-B is equivalent to A+(~B)+1. We can already do A+B+1, so if we add a circuit that can produce ~B, the circuit can also subtract! All of this for only 5 DPDT relays per bit!

# Revision 1.0

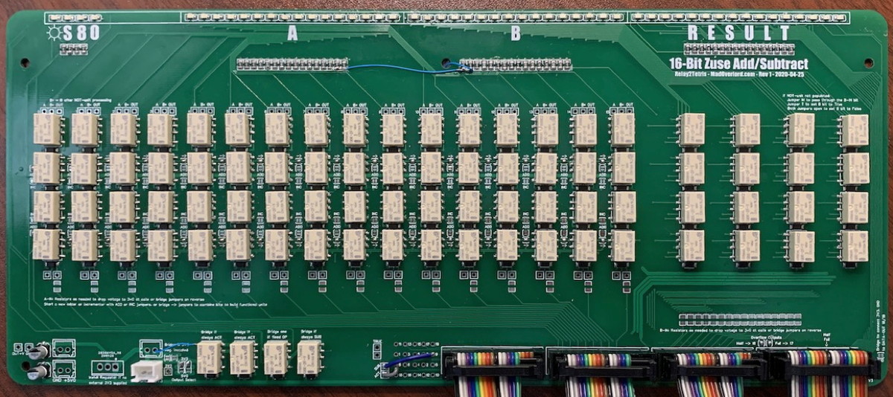
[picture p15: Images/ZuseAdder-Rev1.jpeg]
16 Bit Zuse Adder Rev 1.0


The revision 1.0 Zuse Adder/Subtractor uses the Revision 3.0 Register board as its template, so it has all of the "infrastructure" features of that board.

* 16 Bit Zuse Adder implemented as 4 DPDT relays per bit (+1 if Subtract required)

* Configurable as multiple independent n-bit adders or incrementors. Each bit has solder jumpers that can set the carry-in and not-carry-in to be the start of a new adder, a new incrementor, or carry from the previous bit. So for example, you can configure the board as 2 independent 8-bit adders.

* Optional NOT unit if subtraction is needed; 1 relay per bit.

* Optional outputs for the carry-out of bits 7 and 15 (useful for ALU condition codes).

A short video showing the Revision 1.0 board being tested is available on [YouTube](https://www.youtube.com/watch?v=ZFYi-r_6CD0).

While testing the Revision 1 board, I realized I had made a small mistake. All the relays and the ENABLE LED were connected to ground through the ENABLE relay, but the A and B data display LEDs were connected directly to ground. This meant that when power was provided to the board, there was a path from 3V3 through the power-on LED, then to the ENABLE line, and then backwards through any populated relay or its flyback diode to the associated data display LED, and then to ground. This caused all these LEDs to glow dimly. This did not affect function because as soon as the ENABLE relay connected everything to ground, everything corrected itself.

The solution to this was to cut the data display LED resistor ground connections and wire them to the ENABLE line; this is the blue wire in the photo above.

The other thing I didn't realize at the time was that if all you need is an incrementor, you don't need to populate the two B relays per bit; you just need to bridge their normally-closed pads. I did a quick test of this to create an 8-bit incrementor; a short video is up on [YouTube](https://youtu.be/ckB8yvfqFFo).

# Revision 2.0 / 3.0

16 Bit Zuse Adder Rev 3.0

The Revision 2.0 board design fixes the ground connection problem and adds bridges on the B relays so you can hardwire them to create a fixed adder with any value (with or without the +1 from configuring things as an incrementor). In my test of the incrementor setup, I set up an incrementor with a fixed B input of 0 (I just bridged the pads with small wires) to get a +1 result.

* Note: I created an alternate EasyEDA PCB Library entry for the B relays that included the solder jumpers. This meant they didn't have to be manually added to the schematic.

Note: It turns out there is a design error with the ENABLE circuit in the Rev 2.0 boards that I am working on addressing. See [this note](LogicUnit.md#board-design-mistake) for more details.

A second error is that if the NOT relay array *is* populated but the SUB activation relay *is not* populated, and SUB is not jumpered, the NC SUB relay connections need to be bridged in order for the adder to operate properly. I omitted solder jumpers for this functionality. The workaround is to use some 0-ohm SMT resistors as jumper wires.

I only ran into this error because I fully populated the board to test out the subtract function, and then removed the activation relays to configure the board for use in my prototype ALU.

I then incorporated the lessons from the War on Voltage Drop, resulting in the Rev 3.0 design. The one mistake I've noticed so far is a missing mounting hole in the top-right corner. This has been corrected in the Gerber files.

# Resources

* [The Z1: Architecture and Algorithms of Konrad Zuse’s First Computer](https://arxiv.org/pdf/1406.1886.pdf).

* [Konrad Zuse’s Legacy: The Architecture of the Z1 and Z3](https://www.semanticscholar.org/paper/Konrad-Zuse's-Legacy%3A-The-Architecture-of-the-Z1-Z3-Rojas/be8b813ffdd21a6d75172344f98ce4dcd67b2d44).

* [Board Test Script](/HardwareTests/ZuseAdder.py).

* [EasyEda Project](https://easyeda.com/MadOverlord/zuse-relay-adder), [Gerber Files](/Gerber/ZuseAdder.zip) and [BOM](/BOMs/ZuseAdder.csv) for latest revision of the board.

* Boards were manufactured by [JLCPCB](https://jlcpcb.com/). Parts were sourced from [LCSC](https://lcsc.com/) and [Digikey](https://www.digikey.com/).

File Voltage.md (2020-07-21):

# The War on Voltage Drop

As previously mentioned, I am an electronics n00b. This caused me to make a fundamental -- but fortunately, easily rectifiable -- mistake when originally designing the boards.

I chose to use 3 volt relays in the design because I thought it would make the interconnection to the Raspberry Pi easier, but to my chagrin, it ended up casting my electronics inexperience in a harsher light than I would prefer.

In any circuit, there is a voltage applied across the entire circuit. So for one of my relay circuits, this would typically be about 3.3 volts, as this was the standard signal voltage for the Pi. So if you measure the voltage from the voltage source to the ground, you'd get 3.3 volts.

The relays have a minimum reliable operating voltage of 80% of their rating; in this case that would be 2.4 volts. 3.3 is > 2.4, so this should be okay, right?

Nope.

What counts is the voltage drop across the relay (measured from one side of the relay coil to the other). That has to be at least 2.4 volts. And that voltage depends on the entire circuit.

You can think of the circuit as having three segments in series; the wires leading from the voltage source to the relay, the relay, and the wires leading from the relay to ground. The voltage drop across each segment is proportional to the resistance of each segment - so as long as the resistance of the wires is less than about 28% of the resistance of the relay, the relay will have a voltage drop above our 2.4 volt minimum threshold.

What's the resistance of the coil of the 3 volt relays? 91 ohms. This means that the total resistance of all the wires in series with the coil can only be about 30 ohms. That's not all that much.

But it gets worse. If you drive two relays with the same signal, they are in parallel. This means the resistance across both relays is halved. So now you can only afford 15 ohms of wire resistance. If you are driving three relays, you're down to 10.

Danger, Will Robinson!

There is, however, an easy fix. Returning to the relay data sheet, we are surprised to learn that the coil resistance of the 12 volt relay is... 1315 ohms! Quadrupling the voltage of the coil increases its resistance by 14.5x!

It took me a little while to wrap my pointy head around why this is so. It works like this:

* Both the 3 volt and 12 volt relays consume about the same amount of power.

* Power = Voltage * Current.

* Voltage = Current * Resistance -> Current = Voltage / Resistance.

* So Power = Voltage * Voltage / Resistance.

* Since Power must remain the same, in an ideal world if we 4x the voltage, we have to 16x the resistance.

The end result is that if I switch from 3 volt to 12 volt relays, the relay resistance dominates, and the voltage drops caused by the wiring become much less significant.

Therefore, I am:

* Switching to 12 volt relays. Anyone need any 3 volt relays? I've got a few extras... :(

* Revising all the PCB designs in light of what I've learned; in particular, embiggening the PCB traces as much as possible to reduce their resistance. In addition, the power circuitry has been simplified, with optional on-board regulation, and using either regulated or unregulated power for both the board power and output power.

* Manufacturing the new boards with 2oz copper traces instead of the normal 1oz out of pure paranoia.

* Designing a new IO Expander daughterboard that uses a voltage divider circuit to reduce 12 volt signals coming from the boards down to 3.3 volt signals that can be read directly by the MCP23017 chips.

So far I have received, populated and tested both the Register and Zuse Adder boards using 12 volt relays; the voltage drop caused by the cabling is now negligible. In addition, even with the voltage drop from the MIC2981 drivers on the IO Expander board, when driven by a 12 volt PC power supply (which really only provides 11.7 volts), the voltage is high enough to reliably drive the relays (at least in a single-board test). If this turns out not to be the case in a multi-board configuration, I can provide a separate, slightly higher voltage power supply to the 2981s.

I'd say "Mission Accomplished" but history tells us that saying that doesn't age well. :)

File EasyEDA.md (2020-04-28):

In the process of creating the PCBs for this project, I have created a couple of EasyEDA scripts that are quite useful. You can install scripts into EasyEDA using the Tools > Extensions > Load Scripts... option.

I recommend that you first download Duritskiy's [package of scripts](https://yadi.sk/d/MUeNNxXA4ULpLQ). You may find some of them useful, but in particular there is an Extension (still called "My Extension") that you can install (using Tools > Extensions > Extension Setting...) that adds an icon to the toolbar that lets you easily run any scripts you have loaded.

Available scripts in this repository are:

# [Relink](EasyEDA%20Scripts/relink.js)

A common task when creating the relay circuits is copy/pasting repeated track layouts. The problem is that the tracks and vias retain the original net names, and manually renaming them is tedious. What relink does is look for tracks and vias that have a blank net name and that have an endpoint that coincides with a object that has a net name; it then changes the net name of the track or via to match.

This means you can copy/paste a bunch of tracks, select them, change their net name to be blank (if all the selected objects have a net-name field, you'll be able to edit them using the info display on the left), lay down the new components on top of them (as needed) and then use Relink to fix their net names.

Relink will re-run itself up to 10 times to allow changes to propagate through the blank nets. In rare circumstances you may have to run it a second time.

Notes:

* As of this writing there is a bug in EasyEDA that sometimes sets net names to (null) when you copy/paste an object with a blank net name. Relink will not relink objects with null net names. However, you can fix this by selecting one of the offending objects, using Find Similar... to find other objects with the same null net name, and setting their net name back to blank. You will have to do this for tracks and vias separately.

* Relink only works with endpoints, so a track that passes through a pad without terminating at it will not be relinked.

# [Merge & Simplify](EasyEDA%20Scripts/merge.js)

When a PCB is edited a lot, often tracks will end up composed of a bunch of subtracks, and when you try and rearrange things, you have to rearrange each subtrack. Merge & Simplify will combine tracks with the same net name and a common endpoint. To keep things simple, on each invocation it will only do one combination per net name, so you will have to run it multiple times until it runs out of things to do.

The final time it runs, when it finds no more tracks to merge, it will do a simplify pass on each net, combining segments that share an endpoint and that have the same slope.

Notes:

* The simplify pass can cause two track segments that meet at a pad or hole to be combined into a single segment that passes **through** the pad/hole. This is not a problem for PCB design or fabrication, but can occasionally mean a little extra editing when adjusting the track because it is no longer pinned to the object; if you drag it around, it may slide off the object.

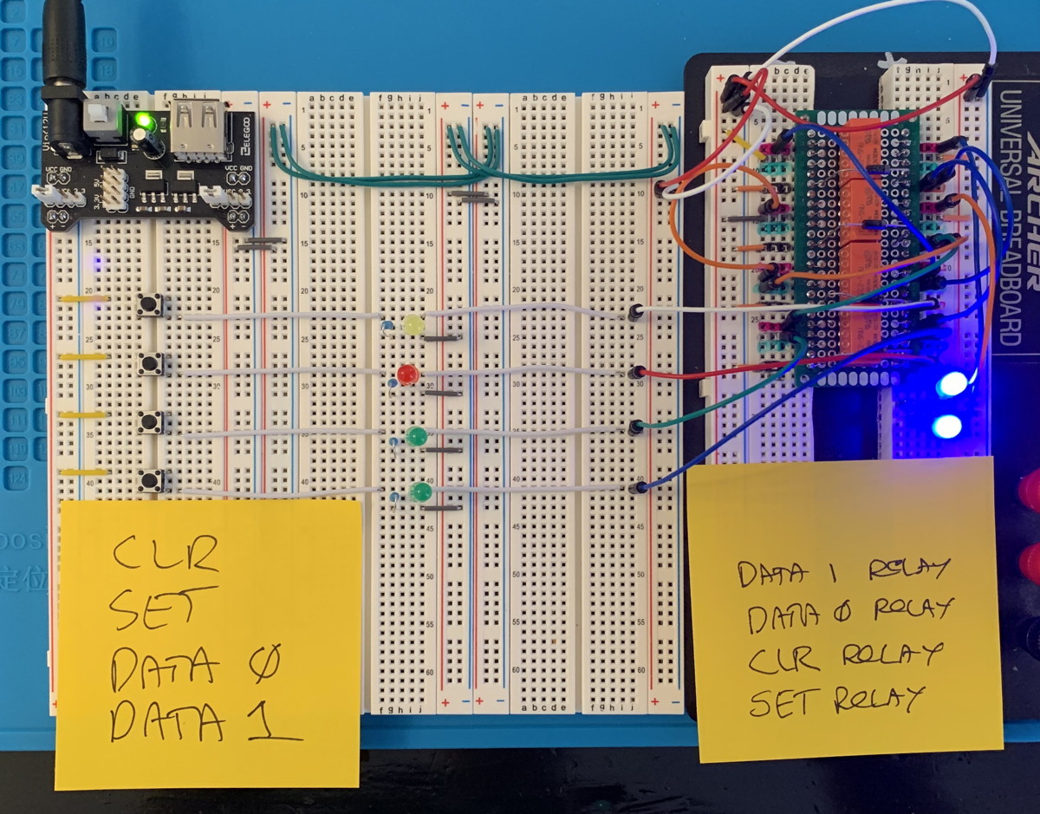
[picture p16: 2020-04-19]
Images/Register-Breadboard.jpeg

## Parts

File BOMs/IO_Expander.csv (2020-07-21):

ID | Name | Designator | Footprint | Quantity | Manufacturer Part | Manufacturer | Supplier | Supplier Part | LCSC Assembly
1 | Header-Female-2.54_1x10 | J1,J2,J3,J4,J5,J6,J7,J8,J9,J10 | HDR-TH_10P-P2.54-V | 10 | 2.54mm 1*10P Straight Female header Gold-plated | BOOMELE | LCSC | C35445
2 | 4.7K | RN-1-1,RN-1-2,RN-1-4,RN-1-3,RN-0-3,RN-0-4,RN-0-2,RN-0-1,RN-TSX-OE2,RN-1-5,RN-1-6,RN-MCP-0,RN-MCP-1,RN-TSX-OE1,RN-OUT-1,RN-OUT-2,RN-OUT-3,RN-OUT-4,RN-OUT-5,RN-OUT-6,RN-OUT-7,RN-OUT-8,RN-OUT-10,RN-OUT-9 | RES-ARRAY-SMD_0603-8P-L3.2-W1.6-BL | 24 | 4D03WGJ0472T5E | UniOhm | LCSC | C1980 | Yes
3 | 100nF | C2,C1 | C0805 | 2 | 0805B104M500 | WTC | LCSC | C94108
4 | MCP23017-E/SO | MCP-1,MCP-0 | SOIC-28_L18.1-W10.3-P1.27-LS10.3-BL | 2 | MCP23017-E/SO | MICROCHIP | LCSC | C47023 | Yes
5 | B2B-XH-A (LF)(SN) | EXT-TSX-OUT,EXT-TSX-IN,EXT-MCP,EXT-MCP1,EXT-TSX-IN1,EXT-TSX-OUT1 | CONN-TH_B2B-XH-A (LF)(SN) | 6 | - | JST Sales America | LCSC | C158012

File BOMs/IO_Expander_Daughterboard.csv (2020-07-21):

ID | Name | Designator | Footprint | Quantity | Manufacturer Part | Manufacturer | Supplier | Supplier Part | LCSC Assembly
1 | MIC2981-TH | MIC1 | DIP-18_NO | 1 |  |  | Amazon
2 | 4.7K | RN1,RN2,RN3,RN4 | RES-ARRAY-SMD_0603-8P-L3.2-W1.6-BL-REV | 4 | 4D03WGJ0472T5E | UniOhm | LCSC | C1980 | Yes

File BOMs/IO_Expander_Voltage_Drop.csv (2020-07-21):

ID | Name | Designator | Footprint | Quantity | Manufacturer Part | Manufacturer | Supplier | Supplier Part
1 | 9.1K | R9,R10,R11,R12,R13,R14,R15,R16 | R0805 | 8 | RK73H2ATTD9101F | KOA Speer Elec | LCSC | C317276
2 | 3.6K | R1,R2,R3,R5,R6,R7,R8,R4 | R0805 | 8 | RK73H2ATTD3601F | KOA Speer Elec | LCSC | C160078

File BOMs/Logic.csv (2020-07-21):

ID | Name | Designator | Footprint | Quantity | Manufacturer Part | Manufacturer | Supplier | Supplier Part | LCSC Assembly
1 | PAD_TERMINAL | CTRL-IN-19,CTRL-IN-18,CTRL-IN-17,CTRL-IN-16,CTRL-IN-15,CTRL-IN-14,CTRL-IN-13,CTRL-IN-12,CTRL-IN-11,CTRL-IN-10,CTRL-IN-9,CTRL-IN-8,CTRL-IN-7,CTRL-IN-6,CTRL-IN-5,CTRL-IN-4,CTRL-IN-3,CTRL-IN-2,CTRL-IN-1,CTRL-IN-0 | CON_PAD_ROUND_32MIL | 20
2 | G6K-2F-Y DC12 | B-0,NOT-0,A-0,A-1,NOT-1,B-1,A-2,NOT-2,B-2,A-3,NOT-3,B-3,A-4,NOT-4,B-4,A-5,NOT-5,B-5,A-6,NOT-6,B-6,A-7,NOT-7,B-7,A-8,NOT-8,B-8,A-9,NOT-9,B-9,A-10,NOT-10,B-10,A-11,NOT-11,B-11,B-12,NOT-12,A-12,B-13,NOT-13,A-13,B-14,NOT-14,A-14,B-15,NOT-15,A-15,XOR,NOT,AND | RELAY-SMD_G6K-2F-Y | 51 | G6K-2F-Y DC12 | OMRON | LCSC | C397194
3 | JUMPER-NO-SM | SJ-XOR-1,SJ-NOT-1,SJ-NOT-2,SJ-AND-1,SJ-XOR-2,SJ-AND-2,SJ-NOT-3,SJ-NOT-4 | SJ_2S-NO | 8
4 | SOLDERJUMPERNO | SJ3,SJ4,SJ2,SJ34,SJ9,SJ8,SJ7,SJ6,SJ35,SJ1,SJ5,SJ29,XOR-0,AND-0,AND-ON-0,XOR-ON-0,NOT-NEVER-0,NOT-ALWAYS-0,NOT-NORMAL-0,NOT-NORMAL-1,NOT-ALWAYS-1,NOT-NEVER-1,XOR-ON-1,AND-ON-1,AND-1,XOR-1,NOT-NORMAL-2,NOT-ALWAYS-2,NOT-NEVER-2,XOR-ON-2,AND-ON-2,AND-2,XOR-2,NOT-NORMAL-3,NOT-ALWAYS-3,NOT-NEVER-3,XOR-ON-3,AND-ON-3,AND-3,XOR-3,OUT-CON-0,OUT-CON-1,OUT-CON-2,OUT-CON-3,NOT-NORMAL-4,NOT-ALWAYS-4,NOT-NEVER-4,XOR-ON-4,AND-ON-4,AND-4,XOR-4,NOT-NORMAL-5,NOT-ALWAYS-5,NOT-NEVER-5,XOR-ON-5,AND-ON-5,AND-5,XOR-5,NOT-NORMAL-6,NOT-ALWAYS-6,NOT-NEVER-6,XOR-ON-6,AND-ON-6,AND-6,XOR-6,NOT-NORMAL-7,NOT-ALWAYS-7,NOT-NEVER-7,XOR-ON-7,AND-ON-7,AND-7,XOR-7,OUT-CON-4,OUT-CON-5,OUT-CON-6,OUT-CON-7,NOT-NORMAL-8,NOT-ALWAYS-8,NOT-NEVER-8,XOR-ON-8,AND-ON-8,AND-8,XOR-8,NOT-NORMAL-9,NOT-ALWAYS-9,NOT-NEVER-9,XOR-ON-9,AND-ON-9,AND-9,XOR-9,NOT-NORMAL-10,NOT-ALWAYS-10,NOT-NEVER-10,XOR-ON-10,AND-ON-10,AND-10,XOR-10,NOT-NORMAL-11,NOT-ALWAYS-11,NOT-NEVER-11,XOR-ON-11,AND-ON-11,AND-11,XOR-11,OUT-CON-8,OUT-CON-9,OUT-CON-10,OUT-CON-11,XOR-12,AND-12,AND-ON-12,XOR-ON-12,NOT-NEVER-12,NOT-ALWAYS-12,NOT-NORMAL-12,XOR-13,AND-13,AND-ON-13,XOR-ON-13,NOT-NEVER-13,NOT-ALWAYS-13,NOT-NORMAL-13,XOR-14,AND-14,AND-ON-14,XOR-ON-14,NOT-NEVER-14,NOT-ALWAYS-14,NOT-NORMAL-14,XOR-15,AND-15,AND-ON-15,XOR-ON-15,NOT-NEVER-15,NOT-ALWAYS-15,NOT-NORMAL-15,OUT-CON-12,OUT-CON-13,OUT-CON-14,OUT-CON-15,BBDJ-0,BBDJ-1,BBDJ-2,BBDJ-3,BBDJ-4,BBDJ-5,BBDJ-6,BBDJ-7,BBDJ-8,BBDJ-9,BBDJ-10,BBDJ-11,BBDJ-12,BBDJ-13,BBDJ-14,BBDJ-15 | SJ_2S-NO | 156
5 | HDR-M-2.54_2x3 | B-R-0,B-R-1,B-R-2,B-R-3,B-R-4,B-R-5,B-R-6,B-R-7,B-R-8,B-R-9,B-R-10,B-R-11,B-R-12,B-R-13,B-R-14,B-R-15,B-R-16,B-R-17,B-R-18,B-R-19,B-R-20,B-R-21 | HDR-RELAY-A | 22 |  |  | LCSC | C65114
6 | G6K-2F-Y-DC12V | CTRL-0 | RELAY-SMD_G6K-2F-Y | 1 | G6K-2F-Y-DC12V | Omron Electronics | LCSC | C397194
7 | G6K-2F-Y DC12 | BBD-0,BBD-1,BBD-2,BBD-3,BBD-4,BBD-5,BBD-6,BBD-7,BBD-8,BBD-9,BBD-10,BBD-11,BBD-12,BBD-13,BBD-14,BBD-15,BBD-16,BBD-17,BBD-18,BBD-19,BBD-20,BBD-21 | RELAY-SMD_G6K-2F-Y | 22 | G6K-2F-Y DC12 | Omron Electronics | LCSC | C397194
8 | HDR-M-2.54_2x4 | B-L-0,B-L-1,B-L-2,B-L-3,B-L-4,B-L-5,B-L-6,B-L-7,B-L-8,B-L-9,B-L-10,B-L-11,B-L-12,B-L-13,B-L-14,B-L-15,B-L-16,B-L-17,B-L-18,B-L-19,B-L-20,B-L-21 | HDR-RELAY-B | 22 |  |  | LCSC | C58363
9 | 1K | R1,R9,R10,R13,R17,R8,R11,R14,R18,R7,R12,R15,R19,R20,R16,R21,R6,R2,R3,R4,R5,R22,R23,R24,R25,R26,R27,R28,R29,R30,R31,R32,R33,R34,R35,R36,R37,R38,R39,R40,R41,R42,R43,R44,R45,R46,R47,R48,R49,R50,R51,R52,R53,R54,R55,R56,R57 | R0805 | 57 | RK73H2ATTD1001F | KOA | LCSC | C160065
10 | HDR-M-2.54_1x1 | JOUT-22,JOUT-16,JOUT-17,JOUT-23,JOUT-1,JOUT-2,JOUT-3,JOUT-4,JOUT-5,JOUT-6,JOUT-15,JOUT-14,JOUT-13,JOUT-12,JOUT-11,JOUT-10,JOUT-9,JOUT-8,JOUT-7,JOUT-18,JOUT-19,JOUT-20,JOUT-21,JOUT-24,JOUT-25,JOUT-26,JOUT-28,JOUT-29,JOUT-30,JOUT-31,JOUT-32,JOUT-27,JOUT-33,JOUT-34,JOUT-35,JOUT-36 | HDR-M-2.54_1X1 | 36 |  |  | LCSC | C81276
11 | 17-21SURC/S530-A3/TR8 | LED-PWR-ON,LED-DISP-15,LED-DISP-14,LED-DISP-13,LED-DISP-12,LED-DISP-11,LED-DISP-10,LED-DISP-9,LED-DISP-8,LED-DISP-7,LED-DISP-6,LED-DISP-5,LED-DISP-4,LED-DISP-3,LED-DISP-2,LED-DISP-1,LED-DISP-0,LED-AND,LED-NOT,LED-XOR | LED0805-R-RD | 20 | 17-21SURC/S530-A3/TR8 | EVERLIGHT | LCSC | C72037
12 | 17-21SURC/S530-A3/TR8 | LED-IN0-14,LED-IN0-13,LED-IN0-12,LED-IN0-11,LED-IN0-10,LED-IN0-9,LED-IN0-8,LED-IN0-7,LED-IN0-6,LED-IN0-5,LED-IN0-4,LED-IN0-3,LED-IN0-2,LED-IN0-1,LED-IN0-0,LED-IN0-15,LED-IN1-11,LED-IN1-10,LED-IN1-9,LED-IN1-8,LED-IN1-7,LED-IN1-6,LED-IN1-5,LED-IN1-4,LED-IN1-3,LED-IN1-2,LED-IN1-1,LED-IN1-0,LED-IN1-12,LED-IN1-13,LED-IN1-14,LED-IN1-15,LED-IN1-16,LED-IN1-17,LED-IN1-18,LED-IN1-19,LED-IN1-20 | LED0805-R-RD | 37 | 17-21SURC/S530-A3/TR8 | EVERLIGHT | LCSC | C72037 | Yes
13 | Header-Male-2.54_1x1 | BOUT-0,BIN-0,AIN-0,AOUT-0,OUT-0,OUT-1,AOUT-1,AIN-1,BIN-1,BOUT-1,OUT-2,AOUT-2,AIN-2,BIN-2,BOUT-2,OUT-3,AOUT-3,AIN-3,BIN-3,BOUT-3,OUT-4,AOUT-4,AIN-4,BIN-4,BOUT-4,OUT-5,AOUT-5,AIN-5,BIN-5,BOUT-5,OUT-6,AOUT-6,AIN-6,BIN-6,BOUT-6,OUT-7,AOUT-7,AIN-7,BIN-7,BOUT-7,OUT-8,AOUT-8,AIN-8,BIN-8,BOUT-8,OUT-9,AOUT-9,AIN-9,BIN-9,BOUT-9,OUT-10,AOUT-10,AIN-10,BIN-10,BOUT-10,OUT-11,AOUT-11,AIN-11,BIN-11,BOUT-11,BOUT-12,BIN-12,AIN-12,AOUT-12,OUT-12,BOUT-13,BIN-13,AIN-13,AOUT-13,OUT-13,BOUT-14,BIN-14,AIN-14,AOUT-14,OUT-14,BOUT-15,BIN-15,AIN-15,AOUT-15,OUT-15 | HDR-1X1/2.54 | 80 | Header-Male-2.54_1x1 | ReliaPro | LCSC | C81276
14 | HDR-M-2.54_1x3 | CR-0 | HDR-RELAY-A1 | 1 |  |  | LCSC | C180248
15 | HDR-M-2.54_1x3 | J24,J23,J22,J21,J20,J19,J18,J17,J16,J15,J14,J13,J12,J11,J10,J9 | HDR-M-2.54_1X3-L | 16 |  |  | LCSC | C180248
16 | HDR-M-2.54_1x3 | J43,J44,J45,J46,J47,J50,J57,J58,J59,J61,J62 | HDR-M-2.54_1X3_NO_OUTLINE | 11 |  |  | LCSC | C180248
17 | HDR-M-2.54_1x5 | J42,J41,J40,J39,J38,J27,J26,J25,J8,J7,J6,J5,J4,J3,J2,J1,J49,J51,J53,J55,J56,J60 | HDR-M-2.54_1X5_NO_OUTLINE | 22 |  |  | LCSC | C358687
18 | JUMPER-NO-SM-REV | RSJ-IN1-0,RSJ-IN1-1,RSJ-IN1-2,RSJ-IN1-3,RSJ-IN1-4,RSJ-IN1-5,RSJ-IN1-6,RSJ-IN1-7,RSJ-IN1-8,RSJ-IN1-9,RSJ-IN1-10,RSJ-IN1-11,RSJ-IN1-12,RSJ-IN1-13,RSJ-IN1-15,RSJ-IN1-14,RSJ-IN0-14,RSJ-IN0-15,RSJ-IN0-12,RSJ-IN0-13,RSJ-IN0-10,RSJ-IN0-11,RSJ-IN0-8,RSJ-IN0-9,RSJ-IN0-6,RSJ-IN0-7,RSJ-IN0-4,RSJ-IN0-5,RSJ-IN0-2,RSJ-IN0-3,RSJ-IN0-0,RSJ-IN0-1 | SJ_2S-NO-REV | 32
19 | 1N4007W | D-XOR,D-NOT,D-AND,D-CTRL-0,D-B-0,D-A-0,D-NOT-0,D-NOT-1,D-A-1,D-B-1,D-NOT-2,D-A-2,D-B-2,D-NOT-3,D-A-3,D-B-3,D-NOT-4,D-A-4,D-B-4,D-NOT-5,D-A-5,D-B-5,D-NOT-6,D-A-6,D-B-6,D-NOT-7,D-A-7,D-B-7,D-NOT-8,D-A-8,D-B-8,D-NOT-9,D-A-9,D-B-9,D-NOT-10,D-A-10,D-B-10,D-NOT-11,D-A-11,D-B-11,D-B-12,D-A-12,D-NOT-12,D-B-13,D-A-13,D-NOT-13,D-B-14,D-A-14,D-NOT-14,D-B-15,D-A-15,D-NOT-15,D-BBD-0,D-BBD-1,D-BBD-2,D-BBD-3,D-BBD-4,D-BBD-5,D-BBD-6,D-BBD-7,D-BBD-8,D-BBD-9,D-BBD-10,D-BBD-11,D-BBD-12,D-BBD-13,D-BBD-14,D-BBD-15,D-BBD-16,D-BBD-17,D-BBD-18,D-BBD-19,D-BBD-20,D-BBD-21 | SOD-123FL_L2.7-W1.8-LS3.8-RD | 74 | 1N4007W | Jingdao | LCSC | C108803 | Yes
20 | HDR-IDC-2.54-2X10P | B-IN,CTRL-IN,A-IN,RESULT | IDC-TH_20P-P2.54-V-R2-C10-S2.54 | 4 | IDC Box 2.54mm 2X10P Straight | BOOMELE | LCSC | C3405
21 | 0 | VD-IN1-0,VD-IN1-1,VD-IN1-2,VD-IN1-3,VD-IN1-4,VD-IN1-5,VD-IN1-6,VD-IN1-7,VD-IN1-8,VD-IN1-9,VD-IN1-10,VD-IN1-11,VD-IN1-12,VD-IN1-13,VD-IN1-15,VD-IN1-14,VD-IN0-14,VD-IN0-15,VD-IN0-12,VD-IN0-13,VD-IN0-10,VD-IN0-11,VD-IN0-8,VD-IN0-9,VD-IN0-6,VD-IN0-7,VD-IN0-4,VD-IN0-5,VD-IN0-2,VD-IN0-3,VD-IN0-0,VD-IN0-1 | R0805 | 32 | RS-05000FT | Guangdong Fenghua Advanced Tech | LCSC | C132364
22 | B2B-XH-A-GU | PWRREG1,PWRUNREG1 | CONN-TH_B2B-XH-A-GU | 2 | B2B-XH-A-GU | JST Sales America | LCSC | C265283
23 | HDR-M-2.54_1x4 | CL-0 | HDR-RELAY-B1 | 1 |  |  | LCSC | C124378
24 | HDR-M-2.54_1x4 | J37,J36,J35,J34,J33,J32,J31,J30,J29,J28,J48,J52,J54 | HDR-M-2.54_1X4_NO_OUTLINE | 13 |  |  | LCSC | C124378

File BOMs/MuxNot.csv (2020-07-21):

ID | Name | Designator | Footprint | Quantity | Manufacturer Part | Manufacturer | Supplier | Supplier Part | LCSC Assembly
4 | G6K-2F-Y-DC12V | NOT-6,NOT,MUX,NOT-15,NOT-14,NOT-13,NOT-12,NOT-11,NOT-10,NOT-9,NOT-8,NOT-7,NOT-5,NOT-4,NOT-3,NOT-2,NOT-1,NOT-0,MUX-01,MUX-23,MUX-45,MUX-67,MUX-89,MUX-1011,MUX-1213,MUX-1415 ,CTRL-1,CTRL-2,BBDA-0,BBDB-0,BBDB-1,BBDA-1,BBDA-2,BBDB-2,BBDA-3,BBDB-3,BBDA-4,BBDB-4,BBDA-5,BBDB-5,BBDB-6,BBDA-6,BBDB-7,BBDA-7,BBDB-8,BBDA-8,BBDB-9,BBDA-9,BBDB-10,BBDA-10,BBDB-11,BBDA-11,BBDB-12,BBDA-12,BBDB-13,BBDA-13,BBDB-14,BBDA-14,BBDB-15,BBDA-15,BBDC-0,BBDC-1,BBDC-2,BBDC-3,BBDC-4,BBDC-5,BBDC-6,BBDC-7,BBDC-8,BBDC-9,BBDC-10,BBDC-11 | RELAY-SMD_G6K-2F-Y | 72 | G6K-2F-Y-DC12V | Omron Electronics | LCSC | C397194
5 | 1K | R2,R4,R5,R6,R7,R8,R9,R10,R11,R12,R13,R14,R15,R16,R17,R18,R19,R20,R21,R49,R48,R47,R46,R45,R44,R43,R42,R41,R40,R39,R38,R37,R36,R35,R34,R33,R32,R31,R30,R29,R28,R27,R26,R25,R24,R23,R22,R1,R3,R50,R51,R-TEST-3,R-TEST-2,R-TEST-1,R-TEST-4,R-TEST-5 | R0805 | 56 | RK73H2ATTD1001F | KOA Speer Elec | LCSC | C160065
8 | 17-21SURC/S530-A3/TR8 | LED-DISP-0,LED-DISP-1,LED-DISP-2,LED-DISP-3,LED-DISP-4,LED-DISP-5,LED-DISP-6,LED-DISP-7,LED-DISP-8,LED-DISP-9,LED-DISP-10,LED-DISP-11,LED-DISP-12,LED-DISP-13,LED-DISP-14,LED-DISP-15,LED-NOT-ON,LED-ENABLE-ON,LED-MUX-ON,LED-TEST-3,LED-TEST-2,LED-TEST-1,LED-TEST-4,LED-TEST-5 | LED0805-R-RD | 56 | 17-21SURC/S530-A3/TR8 | EVERLIGHT | LCSC | C72037
18 | 1N4007W | DNOT-15,DNOT-14,DNOT-13,DNOT-12,DNOT-11,DNOT-10,DNOT-9,DNOT-8,DNOT-7,DNOT-6,DNOT-5,DNOT-4,DNOT-3,DNOT-2,DNOT-1,DNOT-0,D-NOT,D-MUX,D-CTRL-1,D-CTRL-2,D52,D59,D65,D66,D67,D68,D69,D70,D-BBDA-0,D-BBDB-0,D-BBDB-1,D-BBDA-1,D-BBDA-2,D-BBDB-2,D-BBDA-3,D-BBDB-3,D-BBDA-4,D-BBDB-4,D-BBDA-5,D-BBDB-5,D-BBDB-6,D-BBDA-6,D-BBDB-7,D-BBDA-7,D-BBDB-8,D-BBDA-8,D-BBDB-9,D-BBDA-9,D-BBDB-10,D-BBDA-10,D-BBDB-11,D-BBDA-11,D-BBDB-12,D-BBDA-12,D-BBDB-13,D-BBDA-13,D-BBDB-14,D-BBDA-14,D-BBDB-15,D-BBDA-15,D-BBDC-0,D-BBDC-1,D-BBDC-2,D-BBDC-3,D-BBDC-4,D-BBDC-5,D-BBDC-6,D-BBDC-7,D-BBDC-8,D-BBDC-9,D-BBDC-10,D-BBDC-11 | SOD-123FL_L2.7-W1.8-LS3.8-RD | 72 | 1N4007W | Jingdao | LCSC | C108803 | Yes
19 | HDR-IDC-2.54-2X10P | RESULT,A-IN,CTRL-IN,B-IN | IDC-TH_20P-P2.54-V-R2-C10-S2.54 | 4 | IDC Box 2.54mm 2X10P Straight | BOOMELE | LCSC | C3405
21 | B2B-XH-A-GU | PWRUNREG1,PWRREG1 | CONN-TH_B2B-XH-A-GU | 2 | B2B-XH-A-GU | JST Sales America | LCSC | C265283

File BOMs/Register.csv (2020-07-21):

ID | Name | Designator | Footprint | Quantity | Manufacturer Part | Manufacturer | Supplier | Supplier Part | LCSC Assembly
2 | G6K-2F-Y DC12 | TEST-0,TEST-1,TEST-2,TEST-3,TEST-4,TEST-5,TEST-6,TEST-7,TEST-8,TEST-9,TEST-10,TEST-11,TEST-12,TEST-13,TEST-14,TEST-15,EXTRA-2,EXTRA-1,EXTRA-3,EXTRA-4,EXTRA-5,EXTRA-6,EXTRA-7,EXTRA-8,SET-01,BIT-0,BIT-1,BIT-2,BIT-3,CLR-23,SET-23,CLR-01,CLR-45,SET-45,CLR-67,SET-67,BIT-7,BIT-5,BIT-4,BIT-6,CLR-89,SET-89,CLR-1011,SET-1011,BIT-8,BIT-9,BIT-10,BIT-11,CLR-1213,SET1213,CLR-1415,SET-1415,BIT-15,BIT-13,BIT-12,BIT-14,ENABLE,SET,CLR,MUX,ENABLE1,RESET,MUX-01,MUX-23,MUX-45,MUX-67,MUX-89,MUX-1011,MUX-1213,MUX-1415 | RELAY-SMD_G6K-2F-Y | 70 | G6K-2F-Y DC12 | OMRON | LCSC | C397194
5 | 1K | R1,R2,R3,R4,R5,R6,R7,R8,R9,R10,R11,R12,R13,R14,R15,R16,R17,R18,R19,R20,R21,R-TEST-0,R-TEST-1,R-TEST-2,R-TEST-3,R22 | R0805 | 26 | RK73H2ATTD1001F | KOA Speer Elec | LCSC | C160065
8 | 17-21SURC/S530-A3/TR8 | LED-DISP-0,LED-DISP-1,LED-DISP-2,LED-DISP-3,LED-DISP-4,LED-DISP-5,LED-DISP-6,LED-DISP-7,LED-DISP-8,LED-DISP-9,LED-DISP-10,LED-DISP-11,LED-DISP-12,LED-DISP-13,LED-DISP-14,LED-DISP-15,LED-CLR-ON,LED-ENABLE-ON,LED-PWR-ON,LED-SET-ON,LED-MUX-ON,LED-TEST-0,LED-TEST-1,LED-TEST-2,LED-TEST-3,LED-RESET-ON | LED0805-R-RD | 26 | 17-21SURC/S530-A3/TR8 | EVERLIGHT | LCSC | C72037
11 | 1N4007W | D1,D2,D3,D4,D5,D6,D7,D8,D9,D10,D11,D12,D13,D14,D15,D16,D17,D18,D19,D20,D21,D22,D23,D24,D25,D26,D27,D28,D29,D30,D31,D32,D72,D54,D57,D58,D33,D34,D52,D59,D65,D66,D67,D68,D69,D70,D-A1-1,D-A1-2,D-A1-3,D-A1-4,D-A1-5,D-A1-6,D-A1-7,D-A1-8,D-A1-9,D-A1-10,D-A1-11,D-A1-12,D-A1-13,D-A1-14,D-A1-15,D-A1-16,D-A1-18,D-A1-17,D-A1-19,D-A1-20,D-A1-21,D-A1-22,D-A1-23,D-A1-24 | SOD-123FL_L2.7-W1.8-LS3.8-RD | 70 | 1N4007W | Jingdao | LCSC | C108803 | Yes
12 | HDR-IDC-2.54-2X10P | VALUE,A-IN,CTRL-IN,B-IN | IDC-TH_20P-P2.54-V-R2-C10-S2.54 | 4 | IDC Box 2.54mm 2X10P Straight | BOOMELE | LCSC | C3405
14 | B2B-XH-A-GU | PWRUNREG,PWRREG | CONN-TH_B2B-XH-A-GU | 2 | B2B-XH-A-GU | JST Sales America | LCSC | C265283

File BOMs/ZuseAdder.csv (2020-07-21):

ID | Name | Designator | Footprint | Quantity | Manufacturer Part | Manufacturer | Supplier | Supplier Part | LCSC Assembly
2 | G6K-2F-Y DC12 | A2-0,A1-0,A1-1,A2-1,A2-2,A1-2,A1-3,A2-3,A1-10,A2-10,A2-11,A1-11,A2-12,A1-12,A1-13,A2-13,A1-8,A2-8,A2-9,A1-9,A1-14,A2-14,A2-15,A1-15,A1-4,A2-4,A1-5,A2-5,A1-6,A2-6,A1-7,A2-7,SUB1,SUB2,NOT-0,NOT-1,NOT-2,NOT-3,NOT-4,NOT-5,NOT-6,NOT-7,NOT-8,NOT-9,NOT-10,NOT-11,NOT-12,NOT-13,NOT-14,NOT-15 ,B2-0,B1-0,B1-1,B2-1,B1-4,B2-4,B2-5,B1-5,B1-10,B2-10,B2-11,B1-11,B2-12,B1-12,B1-13,B2-13,B1-8,B2-8,B2-9,B1-9,B1-14,B2-14,B2-15,B1-15,B2-2,B1-2,B1-3,B2-3,B1-6,B2-6,B1-7,B2-7 | RELAY-SMD_G6K-2F-Y | 82 | G6K-2F-Y DC12 | OMRON | LCSC | C397194
6 | 1k | R1,R9,R10,R13,R17,R8,R11,R14,R18,R7,R12,R15,R19,R20,R16,R21,R6,R2,R3,R4,R5,R22,R23,R24,R25,R26,R27,R28,R29,R30,R31,R32,R33,R34,R35,R36,R37,R38,R39,R40,R41,R42,R43,R44,R45,R46,R47,R48,R49,R50,R51,R52 | R0805 | 52 | RK73H2ATTD1001F | LIZ | LCSC | C160065
8 | 17-21SURC/S530-A3/TR8 | LED-IN0-14,LED-IN0-13,LED-IN0-12,LED-IN0-11,LED-IN0-10,LED-IN0-9,LED-IN0-8,LED-IN0-7,LED-IN0-6,LED-IN0-5,LED-IN0-4,LED-IN0-3,LED-IN0-2,LED-IN0-1,LED-IN0-0,LED-IN0-15,LED-IN1-11,LED-IN1-10,LED-IN1-9,LED-IN1-8,LED-IN1-7,LED-IN1-6,LED-IN1-5,LED-IN1-4,LED-IN1-3,LED-IN1-2,LED-IN1-1,LED-IN1-0,LED-IN1-12,LED-IN1-13,LED-IN1-14,LED-IN1-15 ,LED-PWR-ON,LED-DISP-15,LED-DISP-14,LED-DISP-13,LED-DISP-12,LED-DISP-11,LED-DISP-10,LED-DISP-9,LED-DISP-8,LED-DISP-7,LED-DISP-6,LED-DISP-5,LED-DISP-4,LED-DISP-3,LED-DISP-2,LED-DISP-1,LED-DISP-0,LED-OVERFLOW,LED-OVERFLOW8,LED-SUB | LED0805-R-RD | 52 | 17-21SURC/S530-A3/TR8 | EVERLIGHT | LCSC | C72037
12 | 1N4007W | D2,D3,D-B2-0,D-B1-0,D-A1-0,D-A2-0,D-A2-1,D-A1-1,D-B1-1,D-B2-1,D-B2-2,D-B1-2,D-A1-2,D-A2-2,D-A2-3,D-A1-3,D-B1-3,D-B2-3,D-A2-4,D-A1-4,D-B1-4,D-B2-4,D-B2-5,D-B1-5,D-A1-5,D-A2-5,D-A2-6,D-A1-6,D-B1-6,D-B2-6,D-B2-7,D-B1-7,D-A1-7,D-A2-7,D-A2-10,D-A1-10,D-B1-10,D-B2-10,D-B2-11,D-B1-11,D-A1-11,D-A2-11,D-B2-12,D-B1-12,D-A1-12,D-A2-12,D-A2-13,D-A1-13,D-B1-13,D-B2-13,D-A2-8,D-A1-8,D-B1-8,D-B2-8,D-B2-9,D-B1-9,D-A1-9,D-A2-9,D-A2-14,D-A1-14,D-B1-14,D-B2-14,D-B2-15,D-B1-15,D-A1-15,D-A2-15,DNOT-0,DNOT-1,DNOT-2,DNOT-3,DNOT-4,DNOT-5,DNOT-6,DNOT-7,DNOT-8,DNOT-9,DNOT-10,DNOT-11,DNOT-12,DNOT-13,DNOT-14,DNOT-15 | SOD-123FL_L2.7-W1.8-LS3.8-RD | 82 | 1N4007W | Jingdao | LCSC | C108803 | Yes
13 | HDR-IDC-2.54-2X10P | B-IN,CTRL-IN,A-IN,RESULT | IDC-TH_20P-P2.54-V-R2-C10-S2.54 | 4 | IDC Box 2.54mm 2X10P Straight | BOOMELE | LCSC | C3405
15 | B2B-XH-A-GU | PWRREG,PWRUNREG | CONN-TH_B2B-XH-A-GU | 2 | B2B-XH-A-GU | JST Sales America | LCSC | C265283

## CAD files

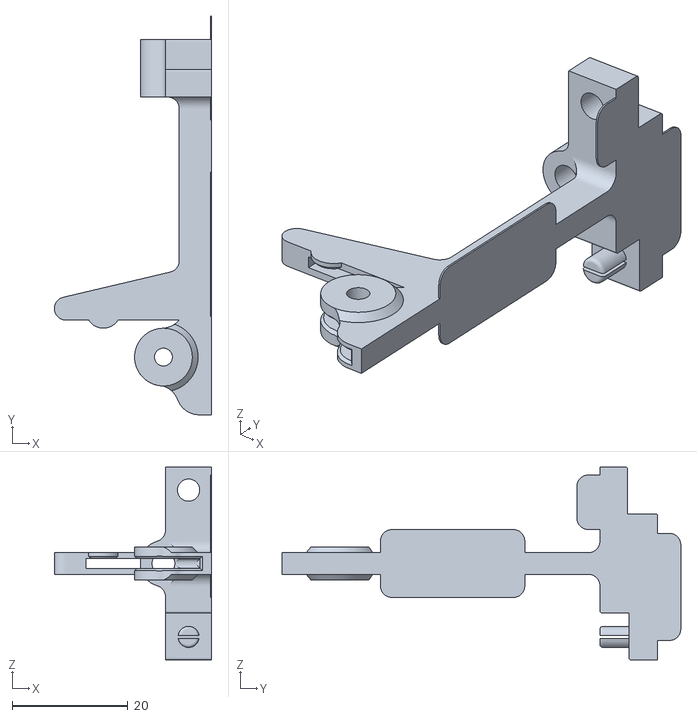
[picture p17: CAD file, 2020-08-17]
STL/PCB Right Bracket v4.stl
27.2 x 69.0 x 33.4

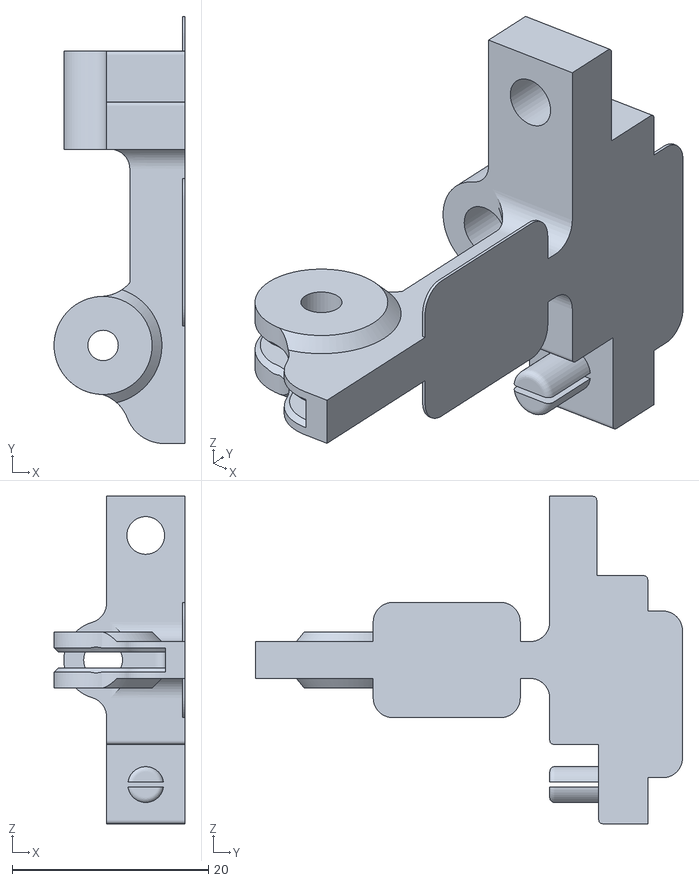
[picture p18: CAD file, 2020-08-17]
STL/PCB Top Bracket v5.stl
13.3 x 43.5 x 33.4

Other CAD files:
STL/PCB Left Bracket v20.stl
STL/PCB Left Bracket v20.f3d
STL/PCB Right Bracket v4.f3d
STL/PCB Top Bracket v5.f3d

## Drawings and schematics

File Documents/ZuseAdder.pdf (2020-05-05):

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

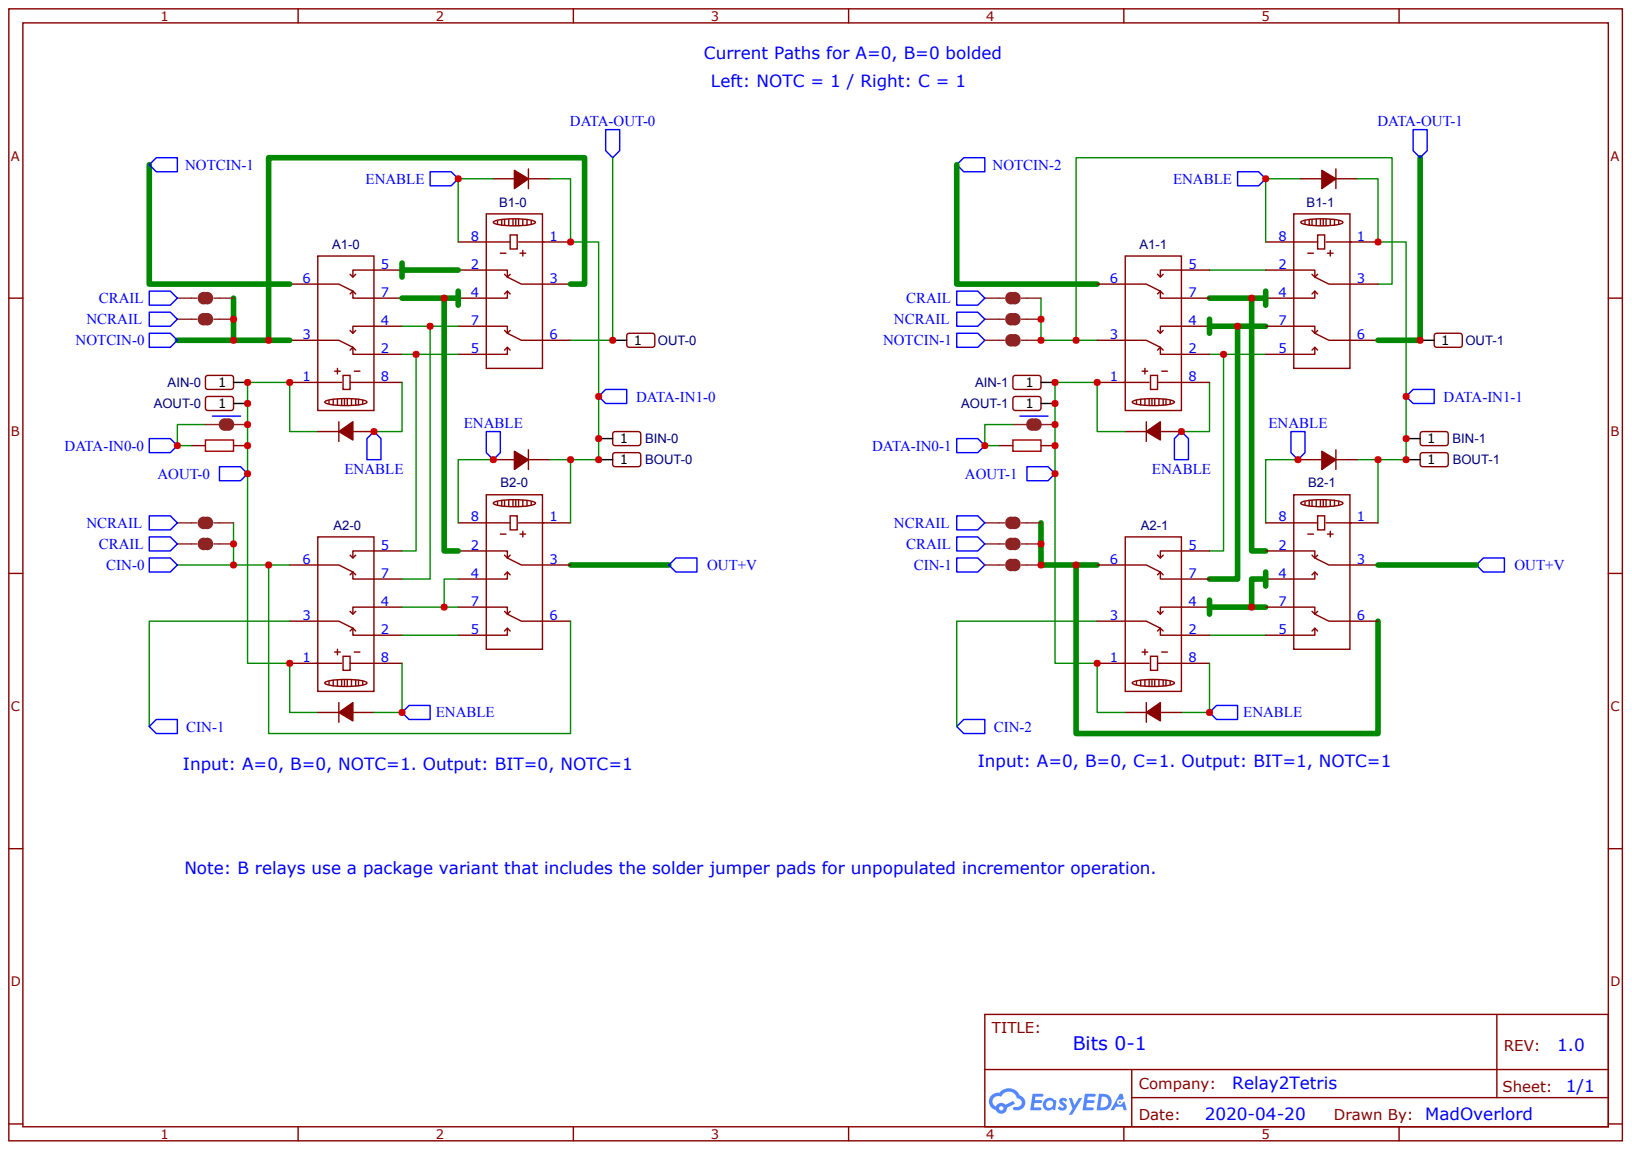
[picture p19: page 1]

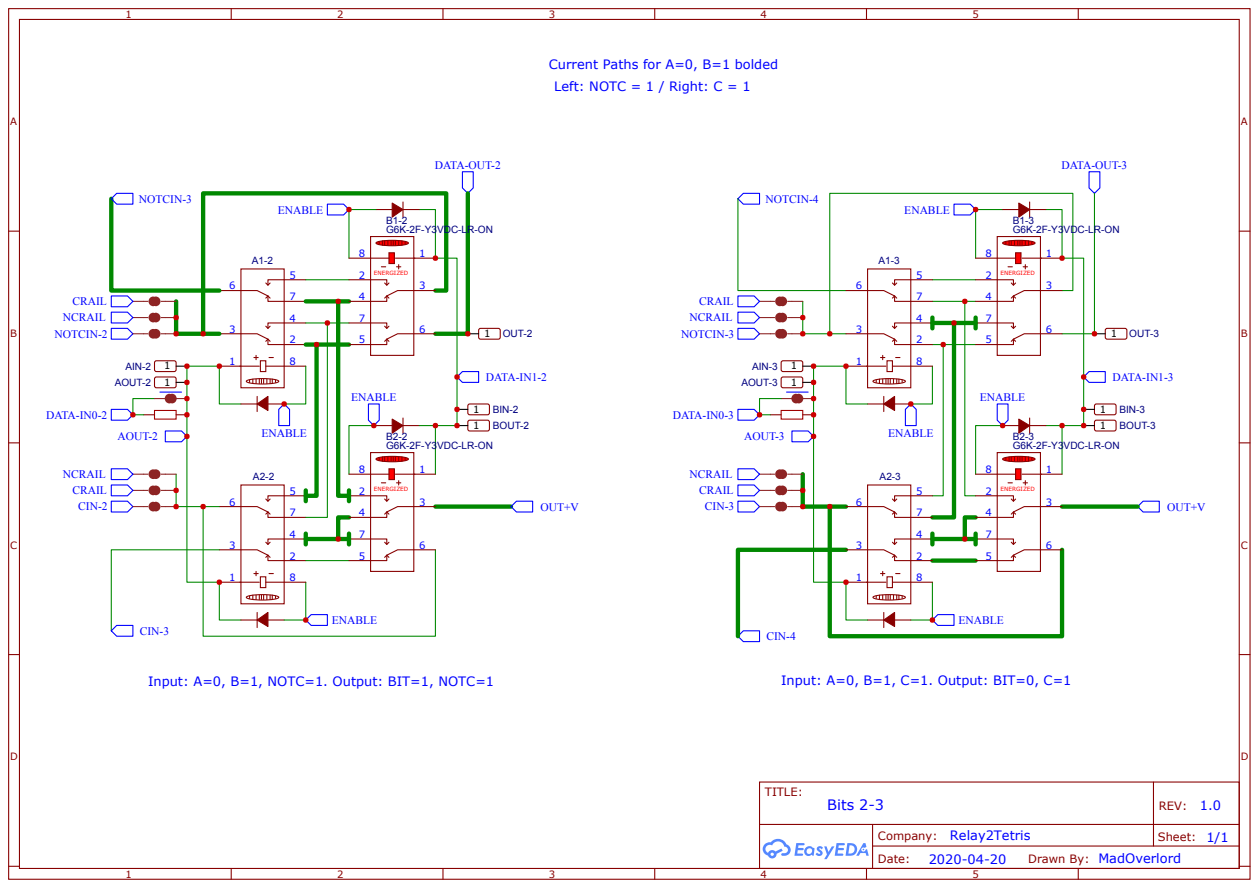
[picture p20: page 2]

7I7LE: BLWV 2-3 | RE9: 1.0

CRPSDQ\: 5HOD\27HWULV | 6KHHW: 1/1

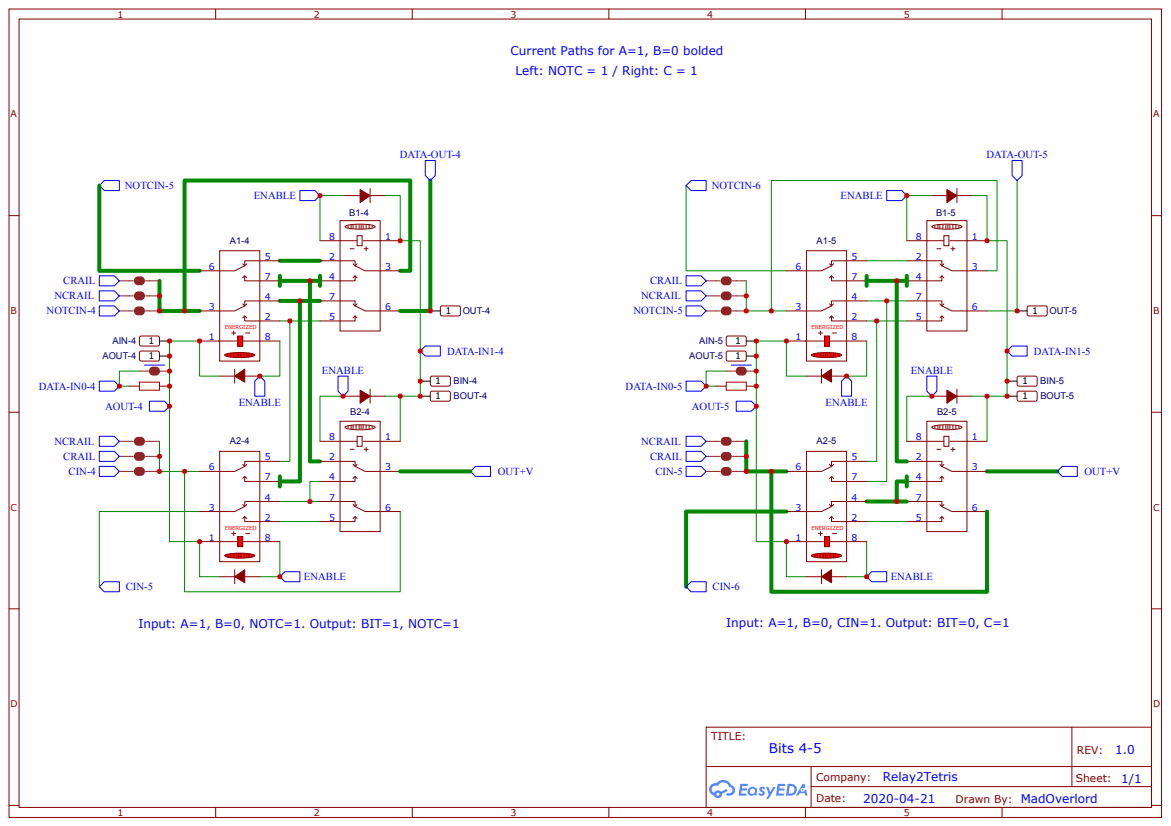
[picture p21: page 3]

7I7LE: BLWV 4-5 | RE9: 1.0

CRPSDQ\: 5HOD\27HWULV | 6KHHW: 1/1

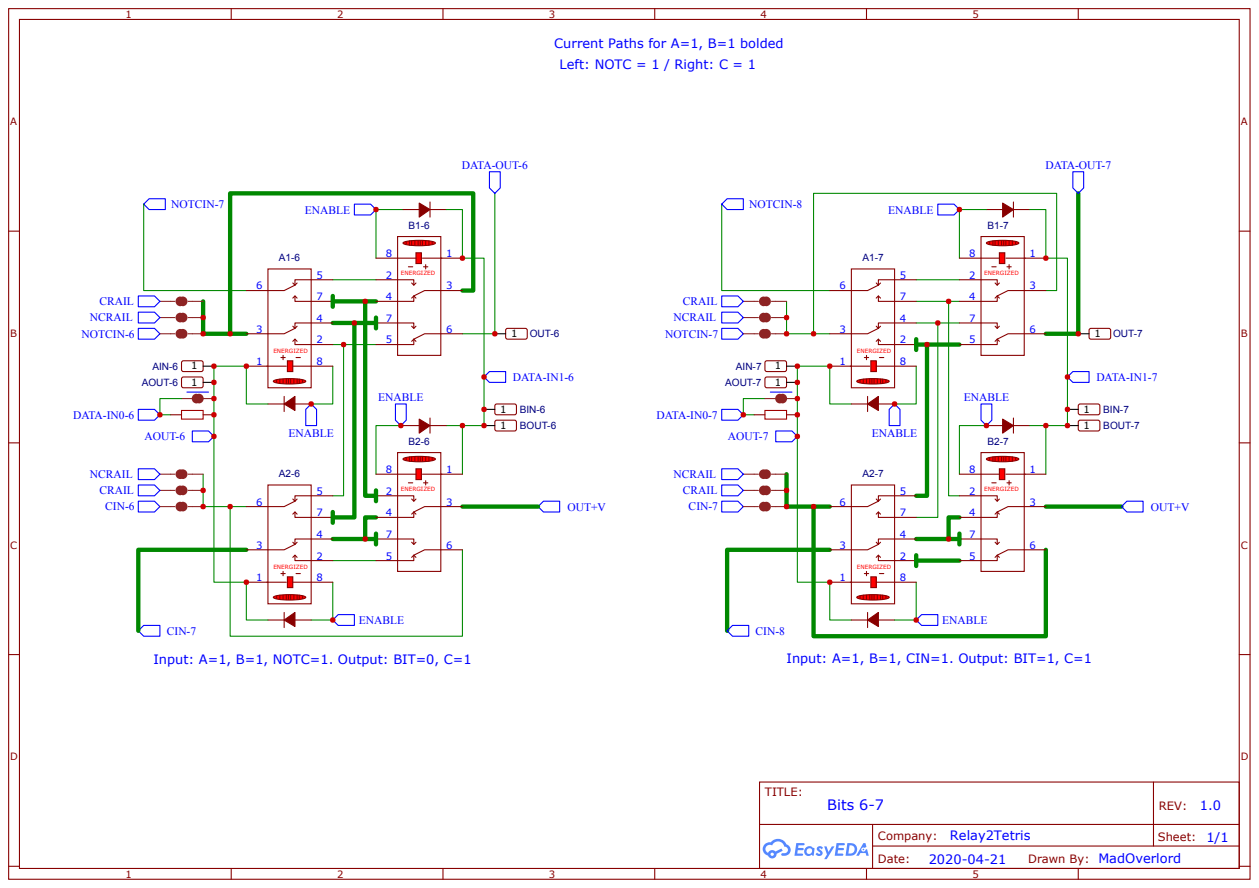
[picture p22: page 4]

7I7LE: BLWV 6-7 | RE9: 1.0

CRPSDQ\: 5HOD\27HWULV | 6KHHW: 1/1
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

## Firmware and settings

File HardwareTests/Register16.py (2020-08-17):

"""
Simple 16 Bit Register board test - for Rev 4.0 boards.
"""

import RPi.GPIO as GPIO
import smbus
import time
import signal
import sys

# Sometimes it is handy to exit without cleaning up, for hardware debugging.

EXIT_DIRTY = False

# Clock tick speed; for demo purposes, we start slow and ramp up.

START_TICK = 0.1      # 0.5 for demos
MAX_TICK = 1 / 200.0
TICK_ACCEL = 0.1

# Delay between reads when debouncing board outputs; None = do not debounce.

DEBOUNCE = 1 / 500.0

# Number of cycles in torture test section.

TORTURE = 25

# IO Expander Port assignments.

DATAIN0 = 0x20  # Main data input to board (value to store)
DATAIN1 = 0x21  # Alt data input to board (value to store if MUX enabled)
DATAOUT = 0x22  # Data output from board (16 bits)
DATACND = None  # Condition codes output from board (None to disable)

ACTIVE_PORTS = [port for port in [DATAIN0, DATAIN1, DATAOUT, DATACND] if port is not None]

bus = smbus.SMBus(1)    # Communications bus.

# GPIO pin hookups - 16 GPIO on 2 boards

gpio_pins = [5, 6, 16, 17, 22, 23, 24, 25, 12, 13, 18, 19, 20, 21, 26, 27]

# Register board control lines (GPIO). When using one of my IO Expander
# boards, the GPIO lines are used for board control. Each board has 8
# IO lines available, in a dual-board setup you get 16. Change these
# depending on what control lines the board being tested uses.


CTL_ENABLE = 1 << 1  # Enable register for CLR/SET
CTL_RESET = 0        # Reset register to 0 even if ENABLE = True. Set to 0 if RESET disabled.
CTL_CLR = 1 << 3     # Clear bits not present on input (release Hold relays)
CTL_SET = 1 << 4     # Set bits present on input (activate Hold relays)
CTL_MUX = 1 << 6     # Select input port. Set to 0 if no MUX installed

# Note that the register can do AND and OR operations. First, you load the
# first value via ENABLE|SET|CLR, ENABLE|SET, ENABLE. Then, after putting
# the next value on the bus, you can ENABLE|SET, ENABLE to OR or ENABLE|CLR,
# ENABLE to AND.

CTL_ALL = CTL_RESET | CTL_ENABLE | CTL_SET | CTL_CLR | CTL_MUX
CTL_NONE = 0

# The sequence of control operations in a store operation. Note that
# the output value does not become stable until the end of the final
# cycle.
#
# This sequence does not include MUX operations.

SEQUENCE = [CTL_NONE,
            CTL_ENABLE | CTL_SET | CTL_CLR,
            CTL_ENABLE | CTL_SET | CTL_CLR,
            CTL_ENABLE | CTL_SET,
            CTL_ENABLE | CTL_SET,
            CTL_NONE]

# MUX-enabled version of SEQUENCE.

SEQUENCE_MUX = [bits | CTL_MUX if bits != CTL_NONE else 0 for bits in SEQUENCE]

# Basic test patterns for the torture test.

PATTERNS = [0b1111111111111111,
            0b0000000000000000,
            0b1010101010101010,
            0b0101010101010101,
            0b1100110011001100,
            0b0011001100110011,
            0b1111000011110000,
            0b0000111100001111,
            0b1111111100000000,
            0b0000000011111111]

# MCP command bytes.

MCP23017_IODIRA = 0x00
MCP23017_IPOLA = 0x02
MCP23017_GPINTENA = 0x04
MCP23017_DEFVALA = 0x06
MCP23017_INTCONA = 0x08
MCP23017_IOCONA = 0x0A
MCP23017_GPPUA = 0x0C
MCP23017_INTFA = 0x0E
MCP23017_INTCAPA = 0x10
MCP23017_GPIOA = 0x12
MCP23017_OLATA = 0x14

MCP23017_IODIRB = 0x01
MCP23017_IPOLB = 0x03
MCP23017_GPINTENB = 0x05
MCP23017_DEFVALB = 0x07
MCP23017_INTCONB = 0x09
MCP23017_IOCONB = 0x0B
MCP23017_GPPUB = 0x0D
MCP23017_INTFB = 0x0F
MCP23017_INTCAPB = 0x11
MCP23017_GPIOB = 0x13
MCP23017_OLATB = 0x15


def sleep(duration):
    """
    A hopefully reasonably accurate sleep function.
    """

    elapsed = time.clock_gettime(time.CLOCK_MONOTONIC_RAW)
    time.sleep(duration)
    elapsed = time.clock_gettime(time.CLOCK_MONOTONIC_RAW) - elapsed


def accel():
    """
    Accelerate from START_TICK to MAX_TICK. Apologies for the side-effect.
    """

    global START_TICK

    result = START_TICK
    START_TICK += (MAX_TICK - START_TICK) * TICK_ACCEL

    return result


def cleanup(signo=None, stack_frame=None):
    """
    Clean up the MCP buses and GPIO, then exit.
    """

    if EXIT_DIRTY:
        sys.exit(0)

    for port in ACTIVE_PORTS:
        bus.write_byte_data(port, MCP23017_IODIRA, 0xFF)
        bus.write_byte_data(port, MCP23017_IODIRB, 0xFF)

    GPIO.setup(gpio_pins, GPIO.IN, pull_up_down=GPIO.PUD_DOWN)

    GPIO.cleanup()
    print("\n")
    sys.exit(0)


# IO Routines...

def configure_bus():
    """
    Configure the MCP registers to default values.
    """

    # Reset to defaults, set ports to input.

    for port in ACTIVE_PORTS:
        for addr in range(22):
            bus.write_byte_data(port, addr, 0xFF if addr <= 1 else 0x00)

    # Set _WRITE pins to output.

    if DATAIN0 is not None:
        bus.write_byte_data(DATAIN0, MCP23017_IODIRA, 0x00)
        bus.write_byte_data(DATAIN0, MCP23017_IODIRB, 0x00)

    if DATAIN1 is not None:
        bus.write_byte_data(DATAIN1, MCP23017_IODIRA, 0x00)
        bus.write_byte_data(DATAIN1, MCP23017_IODIRB, 0x00)

    # Disable pullup on read pins.

    if DATAOUT is not None:
        bus.write_byte_data(DATAOUT, MCP23017_GPPUA, 0x00)
        bus.write_byte_data(DATAOUT, MCP23017_GPPUB, 0x00)

    if DATACND is not None:
        bus.write_byte_data(DATACND, MCP23017_GPPUA, 0x00)
        bus.write_byte_data(DATACND, MCP23017_GPPUB, 0x00)


def send_bus(device, data, invert=False, settle=None, trace=True):
    """
    Write 16 bits of data to a MCP device.
    """

    lo = data % 256
    hi = data // 256

    if trace:
        print(f'DATA_OUT : device={device:02x} hi={hi:08b} lo={lo:08b} invert={invert}')

    # Note: Signals must be inverted to control some relay boards (not mine, though).

    xor = 0xFF if invert else 0x00

    bus.write_byte_data(device, MCP23017_GPIOA, lo ^ xor)
    bus.write_byte_data(device, MCP23017_GPIOB, hi ^ xor)

    # Give time for results to settle.

    if settle is not None:
        sleep(settle)


def get_bus(device, trace=True):
    """
    Read 16 bits of data from a MCP device.
    """

    lo_in = bus.read_byte_data(device, MCP23017_GPIOA)
    hi_in = bus.read_byte_data(device, MCP23017_GPIOB)

    # Debounce input

    if DEBOUNCE is not None:
        lo_in2, hi_in2 = None, None
        while (lo_in != lo_in2) or (hi_in != hi_in2):
            lo_in2, hi_in2 = lo_in, hi_in
            sleep(DEBOUNCE)
            lo_in = bus.read_byte_data(device, MCP23017_GPIOA)
            hi_in = bus.read_byte_data(device, MCP23017_GPIOB)

    if trace:
        print(f'DATA_IN  : device={device:02x} hi={hi_in:08b} lo={lo_in:08b}')

    return 256*hi_in + lo_in


def configure_gpio():
    """
    Configure GPIO pins.
    """

    GPIO.setmode(GPIO.BCM)
    GPIO.setwarnings(False)

    GPIO.setup(gpio_pins, GPIO.OUT, initial=GPIO.LOW)


def send_gpio(data, invert=False, settle=None, trace=True):
    """
    Send 1..N bits of data to the N defined GPIO pins.
    """

    bits = [c == '1' for c in bin(data)[2:]]
    bits.reverse()
    bits = [bits[n] if n < len(bits) else False for n in range(len(gpio_pins))]

    if trace:
        print(f'GPIO_OUT : data={data:0{len(gpio_pins)}b} invert={invert}')

    if invert:
        bits = [not bit for bit in bits]

    GPIO.output(gpio_pins, bits)

    # Give time for results to settle.

    if settle is not None:
        sleep(settle)


def signal_test():
    """
    This is a test routine you can use to raise all the data and control lines so
    you can probe them with a voltmeter on the board. Using MIC2981 @ 5V, you
    should see between 3.0 and 3.6v at the data pins, depending on how many
    relays are being driven. So since MUX is raised, if you plug the data output
    into DATA-IN-1, you'll get a lower value since the data lines will be driving
    relays (and all the outputs will light up). But if you plug the output into
    DATA-IN-0, you'll get a higher voltage on the data pins because the MIC2981
    isn't doing any real work.

    My repurposed PC power supply provides about 5.15v under no-load conditions,
    and sags to 4.75v when signal_test() turns on all the data lines.
    """

    # Change this to change the data pattern being sent out.

    send_bus(DATAIN0, 0xFFFF, invert=False, settle=None, trace=False)
    if DATAIN1 is not None:
        send_bus(DATAIN1, 0xFFFF, invert=False, settle=None, trace=False)
    send_gpio(CTL_ALL, invert=False, settle=None, trace=False)

    # Wait until exited by user.

    print('Raised all signals, CTRL-C to exit. Remember: since MUX raised, data is on second connector...')

    while True:
        sleep(1)


def condition_codes(value):
    """
    Computes the condition codes for any register value. Will vary depending on how you have things wired up.
    """

    return sum([0b0010 if value == 0 else 0,       # register is zero
                0b1000 if value > 32767 else 0,    # negative
                0b0100 if value == 65535 else 0])  # all ones


def test_register_mux(data0, data1, sequence, expected, trace=True, subtrace=False):
    """
    Test the register. Set the data line(s), send the control sequence, and
    check to see if the expected data appears on the output lines.
    """

    expected_conditions = condition_codes(expected) if DATACND is not None else 0

    if trace:
        print(f'REG_OUT: data0={data0:016b}, data1={data1:016b}, expected={expected:016b}:{expected_conditions:04b}')

    # Set up output lines.

    send_bus(DATAIN0, data0, invert=False, settle=None, trace=subtrace)

    if CTL_MUX != 0:
        send_bus(DATAIN1, data1, invert=False, settle=None, trace=subtrace)

    # Adjust settle time

    settle = accel()

    # Send command sequence with individual settle times.

    for control_lines in sequence:
        if trace:
            output = get_bus(DATAOUT, trace=subtrace)
            conditions = get_bus(DATACND, trace=subtrace) if DATACND is not None else 0
            print(f'Control={control_lines}, Settle={settle}, OUTPUT={output:016b}:{conditions:04b}')

        send_gpio(control_lines, invert=False, settle=settle, trace=subtrace)

    # Check if output == expected.

    output = get_bus(DATAOUT, trace=subtrace)
    conditions = get_bus(DATACND, trace=subtrace) if DATACND is not None else 0

    if trace:
        print(f'REG_VAL: data={output:016b}')

    if output != expected or conditions != expected_conditions:
        print(f'Error:  data0={data0:016b}, data1={data1:016b}, expected={expected:016b}:{expected_conditions:04b}, result={output:016b}:{conditions:04b}')

    return output == expected


def test_register(data, trace=False, subtrace=False):
    """
    Test the register, first using the DATA-IN-0 port, and then
    the DATA-IN-1 port if the MUX is present. The other port
    always gets the inverse of the desired data.
    """

    antidata = data ^ 0xFFFF

    results = test_register_mux(data, antidata, SEQUENCE, data, trace, subtrace)

    if CTL_MUX != 0:
        test_register_mux(antidata, data, SEQUENCE_MUX, data, trace, subtrace) and results

    return results


def reset_test():
    """
    Optional test to explore behavior of the reset signal. In the Revision 4.0
    board, RESET doesn't work if SET is also raised.
    """

    test_register_mux(0xFFFF, 0x000, SEQUENCE, 0xFFFF, False, False)

    sleep(1)

    send_gpio(CTL_RESET)

    sleep(1)

    test_register_mux(0xFFFF, 0xFFFF, SEQUENCE, 0xFFFF, False, False)

    sleep(1)

    send_gpio(CTL_RESET | CTL_ENABLE)

    sleep(1)

    test_register_mux(0xFFFF, 0xFFFF, SEQUENCE, 0xFFFF, False, False)

    sleep(1)

    send_gpio(CTL_RESET | CTL_SET)
    sleep(1)

    test_register_mux(0xFFFF, 0xFFFF, SEQUENCE, 0xFFFF, False, False)

    sleep(1)

    send_gpio(CTL_RESET | CTL_ENABLE | CTL_SET)

    while True:
        sleep(1)


"""
Main Program
"""

print(f'Testing 16 bit register (Revision 4.0)...')

signal.signal(signal.SIGINT, cleanup)
signal.signal(signal.SIGTERM, cleanup)

configure_gpio()
configure_bus()

results = (0, 0)

# Signal test routine - uncomment to set all control lines and pause.
# Useful for doing multimeter level checks.

# signal_test()

# Test of reset functionality.

# reset_test()

# Basic tests.

if not test_register(0, trace=True, subtrace=False):
    print('** FAILED ALL-ZEROS TEST')
    cleanup()

print('')

if not test_register(0xFFFF, trace=True, subtrace=False):
    print('** FAILED ALL-ONES TEST')
    sys.exit(0)
    cleanup()

print('')

for b in range(16):
    if not test_register(1 << b, trace=True, subtrace=False):
        print(f'** FAILED {1 << b:016b} BIT TEST')
        cleanup()
    print('')


tests = 18
loops = 0

while True:

    # Rotation Test.

    for w in range(1, 15):
        base = sum([1 << n for n in range(w)])
        for s in range(16):
            if not test_register(base, trace=False):
                print(f'*** FAILED AFTER {tests} tests!')
                cleanup()
            tests += 1
            base = base << 1
            if base >= 65536:
                base = base - 65535

    # Torture Tests.

    for w in range(1, TORTURE):
        b = test_register(0b0000000000000000, trace=False)
        b = b & test_register(0b1111111111111111, trace=False)
        if not b:
            print(f'*** FAILED AFTER {tests} tests!')
            cleanup()
        tests += 2

    for w in range(1, TORTURE):
        b = test_register(0b1010101010101010, trace=False)
        b = b & test_register(0b0101010101010101, trace=False)
        if not b:
            print(f'*** FAILED AFTER {tests} tests!')
            cleanup()
        tests += 2

    for w in range(1, TORTURE):
        b = test_register(0b1100110011001100, trace=False)
        b = b & test_register(0b0011001100110011, trace=False)
        if not b:
            print(f'*** FAILED AFTER {tests} tests!')
            cleanup()
        tests += 2

    for w in range(1, TORTURE):
        b = test_register(0b1111000011110000, trace=False)
        b = b & test_register(0b0000111100001111, trace=False)
        if not b:
            print(f'*** FAILED AFTER {tests} tests!')
            cleanup()
        tests += 2

    for w in range(1, TORTURE):
        b = test_register(0b1111111100000000, trace=False)
        b = b & test_register(0b0000000011111111, trace=False)
        if not b:
            print(f'*** FAILED AFTER {tests} tests!')
            cleanup()
        tests += 2

    test_register(0b0000000000000000, trace=False)

    loops += 1
    print(f'Loop {loops} completed; {tests} tests performed!')

cleanup()

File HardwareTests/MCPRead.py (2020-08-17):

"""
Read MCP chip(s) and report their values.
"""

import smbus
import time
import signal
import sys


# List of MCPs to poll.

MCPs = [0x22]

# How often do we poll?

RATE = 0.01

# MCP Control Codes.

MCP23017_IODIRA = 0x00
MCP23017_IPOLA = 0x02
MCP23017_GPINTENA = 0x04
MCP23017_DEFVALA = 0x06
MCP23017_INTCONA = 0x08
MCP23017_IOCONA = 0x0A
MCP23017_GPPUA = 0x0C
MCP23017_INTFA = 0x0E
MCP23017_INTCAPA = 0x10
MCP23017_GPIOA = 0x12
MCP23017_OLATA = 0x14

MCP23017_IODIRB = 0x01
MCP23017_IPOLB = 0x03
MCP23017_GPINTENB = 0x05
MCP23017_DEFVALB = 0x07
MCP23017_INTCONB = 0x09
MCP23017_IOCONB = 0x0B
MCP23017_GPPUB = 0x0D
MCP23017_INTFB = 0x0F
MCP23017_INTCAPB = 0x11
MCP23017_GPIOB = 0x13
MCP23017_OLATB = 0x15

bus = smbus.SMBus(1)


def cleanup(signo=None, stack_frame=None):
    """
    Clean up the MCP buses, then exit.
    """

    for mcp in MCPs:
        bus.write_byte_data(mcp, MCP23017_IODIRA, 0xFF)
        bus.write_byte_data(mcp, MCP23017_IODIRB, 0xFF)

    print("\n")
    sys.exit(0)


def read_mcp(receiver, previous, masklsb, maskmsb, loop_count, trace=False):
    """
    Read a MCP (debouncing signal) and display value
    """

    lsb = bus.read_byte_data(receiver, MCP23017_GPIOA) & masklsb
    msb = bus.read_byte_data(receiver, MCP23017_GPIOB) & maskmsb

    lsb2 = bus.read_byte_data(receiver, MCP23017_GPIOA) & masklsb
    msb2 = bus.read_byte_data(receiver, MCP23017_GPIOB) & maskmsb

    while (lsb != lsb2) or (msb != msb2):
        lsb, msb = lsb2, msb2
        lsb2 = bus.read_byte_data(receiver, MCP23017_GPIOA) & masklsb
        msb2 = bus.read_byte_data(receiver, MCP23017_GPIOB) & maskmsb

    results = (msb << 8) + lsb

    if trace:
        prev = f' != {previous:016b}' if results != previous and previous is not None else ''
        print(f'{loop_count:03d} : MCP 0x{receiver:02x} & 0x{maskmsb:02x}{masklsb:02x}: {results:016b}{prev}')

    return results


"""
Main Program
"""

# Configure the MCP registers to default values, and set to input, no pullup.

for mcp in MCPs:
    for addr in range(22):
        bus.write_byte_data(mcp, addr, 0xFF if addr < 2 else 0x00)

# Configure for cleanup on program termination.

signal.signal(signal.SIGINT, cleanup)
signal.signal(signal.SIGTERM, cleanup)

# Perform tests.

loop_count = 1
previous = {receiver: None for receiver in MCPs}

while True:
    for receiver in MCPs:
        previous[receiver] = read_mcp(receiver, previous[receiver], 0xFF, 0xFF, loop_count, True)
    loop_count = (loop_count + 1) % 1000
    time.sleep(RATE)

cleanup()

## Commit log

2020-04-15 Added details of IO Expander Board
2020-05-23 Logic Unit / 2:1 MUX+NOT
    Added two new boards
2020-05-23 Update MuxNot.md
    Typo in Gerber link
2020-07-21 July Update
    Fighting the War on Voltage Drop, redesigning boards, and more.
    [IO_Expander_Daughterboard_Rev_1.0.csv, IO_Expander_Rev_2.0.csv, IO_Expander_Voltage_Drop_Rev_1.0.csv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]
2020-08-05 August 2020 Update
    Updated all the board design documents, improved the hardware tests, did some project cleanups. Added a project status video.
    [IO_Expander.csv, IO_Expander_Daughterboard.csv, IO_Expander_Daughterboard_Rev_1.0.csv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]
2020-08-06 Logic 2.1
    Updated Gerber to fix a label error.
2020-08-17 ALU-lelujah!
    Assembled and tested the ALU!
    [PCB Left Bracket v20.f3d, PCB Left Bracket v20.stl, PCB Right Bracket v4.f3d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]
2020-09-05 Add Condition Code Tests
    Added tests for correct condition codes to the ALU test script.
    [ALU.py]
